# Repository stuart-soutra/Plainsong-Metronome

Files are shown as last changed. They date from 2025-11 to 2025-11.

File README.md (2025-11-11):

# Plainsong-Metronome
Open-source STM32-based digital stereo metronome
## Details
The Plainsong Metronome is a STM32F401-based audio platform, intended to be developed as a hi-fidelity digital stereo metronome for musicians.
The PCB contains two encoders intended to be used for UI navigation and volume control.
Four mechanical keyboard switches are included that are intended to control UI item selection and playback settings.
The PCB can be powered by a 12VDC 1A supply via, the DC barrel jack. 
Two 2.54mm pin header connectors are included for speaker outputs (L and R), as well as an extra 3-pin 2.54mm header (intended to be connected to a pane-mounted 3.4mm stereo TRS jack output for headphones).
The board houses an FFC connector to allow ribbon cable connection to a MIDAS OLED display.
A Micro B USB jack is included to allow firmware upgrade via. STM32 DFU, and potentially sample loading.
A mechanical enclosure design is available for the device (see 'Enclosure').
## Project Status
The project is currently in its B rev - board bring-up has been done in Rev A and Rev B has all changes implemented. 
I started this project to learn more about more complex 4-layer mixed-signal PCB design, so the full firmware was not my primary concern. I have therefore decided to make this project open-source, as I have learnt what I wanted to learn from it and if anyone else would like to dive deeper with the firmware, they can potentially also get something out of this project or take it further.
## Hardware Summary
### STM32F401CBU7 MCU
The MCU processes all IO and uses I2C, I2S and SPI to interface with the OLED, CODEC and Flash memory, respectively. The flash memory is included to expand audio sample storage capacity.
### MAX9867 Audio CODEC
The CODEC handles DAC duties for the system - samples are transmitted to it from the MCU via. I2S, then output to the audio amplifiers. Volume control is handled by the CODEC (with commands coming from the MCU).
### MAX9716 Audio Amplifiers
Two audio amps give differential audio outputs for the speakers (delivering 1.4W into 4 Ohms).
### MIDAS SSD1309ZC-Based OLED
The FFC connector on the board allows for connection of a 31-pin MIDAS OLED (MCOT128064B1V used during testing).
## Current Status
### Rev A
Board bring up was performed during Rev A. I have one Rev A board with all mods implemented that are required for the hardware to work - these changes have been implemented into the Rev B design. I have a number of Rev A boards (unmodded, unpopulated) - feel free to contact me if you would like one of these. I am happy to ship these to the UK if you would like to populate and mod them.
### Rev B
Rev B contains all of the mods from Rev A bring-up (see schematic for more details). The one untested part of the hardware that I have changed between rev's is the audio amplifier circuit. Rev B has a simplified circuit here, as I did not realise that the volume control could be done solely by the CODEC, so the digi-pots are no longer required.
## Untested Components
New Rev B audio amplifier circuit.
## Test Firmware Included
I have included the main test firmware file for STM32 Cube IDE. This includes simple drivers for some of the functions of each of the peripherals on the board that required testing during bring-up. The basic RTOS operation is also tested here. You will find the different test functions to be commented in/out.
## Firmware Build and Upload Process
The easiest way is using STM32 Cube IDE and USB DFU. Hold down the upload button and the SELECT button to access the DFU bootloader whilst power-cycling.
## Future Feature Wishlist
Feel free to help and contribute with these features:
- Audio amplifier circuit testing
- Full operational code
- Sample uploading option added
- External software for sample uploading
## Licence
This project is released under the CERN OHL V2 - Strongly Reciprocal Licence - see 'LICENCE.txt' for full terms.
## PCB Artwork Disclaimer
This project includes original fan artwork inspired by The Cure’s album Wish and Robert Smith’s imagery. It is used here non-commercially, as a tribute, for educational and artistic purposes.

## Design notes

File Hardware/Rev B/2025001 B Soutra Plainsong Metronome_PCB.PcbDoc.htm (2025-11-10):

Reporting Options

# File in Newer Format

Date | : | 26/05/2025
Time | : | 23:38:41
Filename | : | C:\Users\Stuart\OneDrive - Edinburgh Napier University\Altium Projects\2024001 A Soutra Plainsong Metronome\2024001 A Soutra Plainsong Metronome\2024001 A Soutra Plainsong Metronome_PCB.PcbDoc

Version | Warning
Release 23.6 | CAUTION - The PCB document contains Footprint parameters. These will be lost when opening the document in a version of Altium Designer that does not support this functionality.
Release 23.10 | CAUTION - This document contains rules defined using the Constraint Manager. These will appear as standard query-based rules in this version of the software. If you save the PCB document in this older version, then all Constraint Manager data structure information will be lost.

This file was generated by a later version of the software

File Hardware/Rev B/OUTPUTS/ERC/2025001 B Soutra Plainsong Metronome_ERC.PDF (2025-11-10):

### Electrical Rules Check Report

Class | Document | Message
Warning | Block Diagram.SchDoc | Net MCLK_EN has no driving source (Pin R5-1, Pin U1-10, Pin X2-1)
Warning | Block Diagram.SchDoc | Nets Wire D_N has multiple names (Net Label D_N, Sheet Entry Designator-D-(I/O) (2))
Warning | Block Diagram.SchDoc | Nets Wire D_P has multiple names (Net Label D_P, Sheet Entry Designator-D+(I/O) (2))
Warning | Power.SchDoc | Off grid J1 at 912.992mil,6699.213mil
Warning | MCU.SchDoc | Off grid Net Label BOOT0 at 4512.258mil,5300mil
Warning | MCU.SchDoc | Off grid Net Label D_N at 3000.661mil,3600mil
Warning | Power.SchDoc | Off grid Pin J1-1 at 1112.992mil,6799.213mil
Warning | Power.SchDoc | Off grid Pin J1-2 at 1112.992mil,6599.213mil
Warning | Power.SchDoc | Off grid Pin J1-3 at 1112.992mil,6699.213mil
Warning | Power.SchDoc | Off grid Pin SW1-1 at 1829.135mil,6799.216mil
Warning | Power.SchDoc | Off grid Pin SW1-2 at 2429.135mil,6799.216mil
Warning | IOa.SchDoc | Off grid Port D+ at 4099.339mil,6600mil
Warning | MCU.SchDoc | Off grid Port TEMPO_LED at 3390.3mil,3300mil
Warning | Power.SchDoc | Off grid Power Object GND at 1112.992mil,6405.512mil
Warning | Power.SchDoc | Off grid Power Object GND at 4500mil,5618.113mil
Warning | Block Diagram.SchDoc | Off grid Sheet Symbol Designator at 2700mil,6055.515mil
Warning | Power.SchDoc | Off grid SW1 at 2129.135mil,6799.216mil
Thursday 6 Nov 2025 4:35:00 PM | Page 1 of 1

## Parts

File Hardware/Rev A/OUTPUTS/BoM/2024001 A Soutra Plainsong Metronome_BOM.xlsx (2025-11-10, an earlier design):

 |  | Bill of Materials for: |  | Bill of Materials for Project [2024001 A Soutra Plainsong Metronome.PrjPcb] (No PCB Document Selected)
 |  | Source Data From: |  | 2024001 A Soutra Plainsong Metronome.PrjPcb
 |  | Variant: |  | None
 |  | Report Date: |  | 22/10/2024 | 09:38
 | soutraelectronics@gmail.com
 | 14 Ryehill Gardens
 | Edinburgh
 | EH68ER
 | +44(0)7874693650
 |  |  |  |  |  |  | Primary Supplier |  |  | Secondary Supplier |  |  | Alternative Part Details
Designator | Manufacturer Part Number | Value | Manufacturer | Footprint | Quantity | Notes | Supplier | Supplier Part Number | Pricing | Supplier 1 | Supplier Part Number 1 | Pricing 1 | Alternative Part | Alternative Part Manufacturer | Alternative Part Supplier | Alternative Part Supplier Part Number
C3, C4, C9, C13, C42, C43 | CL31B475KAHNNNE | 4.7uF | Samsung | CC1206-IPC_A | 6 |  | Digikey | 1276-1055-1-ND | 1=0.18, 10=0.116, 50=0.0732, 100=0.0585, 500=0.04228, 1000=0.0374 (USD) | Farnell | 3013532 | 5=0.08, 50=0.05
C6 | GRM21BR61A226ME51L | 22uF | Murata | CAPC2012X14L | 1 |  |  |  |  | Farnell | 2494270 | 5=0.192, 50=0.09 | C2012X5R1A226M125AB | TDK | Farnell | 2525131
C7, C8, C18, C22, C23, C24, C26, C27, C28, C29, C37, C38, C41 | CC0402KRX5R6BB105 | 1uF | Yageo | CAPC1005X06L | 13 |  | Farnell | 1458896 | 10=0.039, 100=0.023 | Digikey | 311-1439-1-ND | 1=0.08, 10=0.058, 50=0.034, 100=0.027 | 0402ZD105KAT2A | KYOCERA AVX | Farnell | 1740588
C10, C11, C12, C14, C15, C16, C17, C19, C25, C44 | 0402X104M160CT | 100nF | Walsin Technologies | CAPC1005X06L | 10 |  | Farnell | 2524808 | 10=0.0047, 100=0.0043 | Digikey | 1292-0402X104M160CT-ND | 1=0.08, 10=0.023, 50=0.013, 100=0.01 | 885012105016 | WURTH | Farnell | 2533933
C20, C21 | CC0402CRNPO9BN5R0 | 5pF | Yageo | CAPC1005X06L | 2 |  |  |  |  | Farnell | 3369083 | 10=0.014, 100=0.008 | GJM1555C1H5R0CB01D | Murata | Farnell | 3346199
C30 | CC0402MRX5R5BB225 | 2.2uF | Yageo | CAPC1005X06L | 1 |  |  |  |  | Farnell | 3369189 | 10=0.0794, 100=0.0451 | MC0402X225M6R3CT |  | Farnell | 1759376
C31, C32, C39, C40 | CC0402KPX7R9BB221 | 220pF | Yageo | CAPC1005X06L | 4 |  |  |  |  | Farnell | 4254872 | 10=0.0069, 500=0.0055, 2500=0.0042, 10000=0.003, 25000=0.0029, 50000=0.0028, 250000=0.0027, 500000=0.0026 (GBP) | MC0402B221K500CT |  | Farnell | 1758981
C33, C34, C35, C36 | TAJR225K016RNJ | 2.2uF | AVX Interconnect / Elco | CAPC2113X120X50ML20T30 | 4 |  |  |  |  | Farnell | 2112773 | 5=0.3684, 50=0.2592
D1 | SMAJ13CAHM3_A/H |  | Vishay | SODFL511X229-2N | 1 |  |  |  |  | Farnell | 3530003 | 5=0.168, 10=0.146, 100+0.122
D4, D5, D6, D7, D10 | MP008282 |  | Multicomp | DIOC_0603_1706X06L | 5 |  | Farnell | 3796313 | 5=0.0713, 10=0.0611, 100=0.0476 |  |  |  | LG Q396-PS-35 | AMS OSRAM GROUP | Farnell | 2575345
F1 | MP001600 |  | Multicomp | FUSE_3216X08L | 1 |  | Farnell | 3285103 | 5=0.094, 50=0.0739, 250=0.0627, 500=0.0559, 1500=0.0459 (GBP)
J1 | 694103303002 |  | Wurth Electronics | WURTH_694106301002 | 1 |  | Farnell | 2472149 | 1=1.14, 10=0.84, 100=0.78 | Digikey | 732-5930-ND | 1=0.81, 10=0.77, 50=0.68, 100=0.63
J2, J3 | 22-05-7028 |  | Molex | J_MOLEX_22-05-7028 | 2 |  |  |  |  | Farnell | 9731601 | 1=0.78, 10=0.64, 50=0.57, 100=0.50
J4 | 105017-0001 |  | Molex | 1050170001_USB-MICRO-B_V | 1 |  | Farnell | 3500663 | 1=0.97 | Rs | 8486764 | 5=0.754, 75=0.67
J5 |  |  |  | J_GENERIC_PIN-HEADER_2.54_1X3 | 1
J6 | 3-1734592-1 |  | TE Connectivity | AMP-TE_3-1734592-1 | 1 |  |  |  |  | Farnell | 3398664 | 1=1.44, 10=1.26, 100=1.15
R1, R14, R15, R16, R17, R18, R19, R20, R21, R22, R23, R24, R25, R26, R27, R28, R29 | MC0063W06030R | 0R | Multicomp | RESC_0603_1608X06L | 17 |  | Farnell | 9331662 | 10=0.007, 100=0.006 |  |  |  | MCWR06X000 PTL | Multicomp Pro | Farnell | 2447743
R2, R3 | RK73B1JTTD103J | 10kR | KOA Speer | RESC_0603_1608X06L | 2 |  | Farnell | 4009056 | 10=0.009, 100=0.003 | Digikey | 2019-RK73B1JTTD103JCT-ND | 1=0.08, 10=0.012, 50=0.0078, 100=0.0064 | RMCF0603FT10K0 | Stackpole Electronics Inc | Digikey | RMCF0603FT10K0CT-ND
R4, R5, R6, R8, R9, R31, R32, R33, R34, R35, R36, R37, R42, R43, R44 | RC0805JR-0710KL | 10kR | Yageo | RESC_0805_2013X50X30LL20T20 | 15 |  | Farnell | 9234136 | 10=0.013, 100=0.007, 500=0.006 | Digikey | 311-10KARCT-ND | 1=0.08, 10=0.018, 50=0.011, 100=0.009 | MCMR08X103 JTL |  | Farnell | 2073612
R7 | CRGH0805F2K7 | 2.7k | TE Connectivity | RESC_0805_2013X50X30LL20T20 | 1 |  | Farnell | 2332077 | 10=0.0381 | Mouser | 279-CRGH0805F2K7 | 1=0.096, 10=0.065, 100=0.033 | MC01W08051100R | Multicomp Pro | Farnell | 9332375
R10, R11, R12, R13 | MCMR06X512JTL | 5.1kR | Multicomp | RESC_0603_1608X06L | 4 |  |  |  |  | Farnell | 2073528 | 10=0.0065, 100=0.0056, 500=0.0047, 1000=0.004, 2500=0.0027, 5000=0.0021, 25000=0.0016, 50000=0.0013 (GBP) | MCMR06X5101FTL |  | Farnell | 2073522
R30 | RC0402FR-07590KL | 590kR | Yageo | RESC_0402_1005X40X25LL05T10 | 1 |  |  |  |  | Farnell | 3951243 | 10=0.0096, 100=0.0055 | CRCW0402590KFKED | Vishay | Farnell | 2141013
R38, R39, R40, R41, R45 | CRCW0805100RFKTA | 100R | Vishay Dale | RESC_0805_2013X50X30LL20T20 | 5 |  | Farnell | 1652906 | 10=0.06, 100=0.026 | Mouser | 71-CRCW0805-100 | 1=0.12, 10=0.042, 100=0.027 | CRCW0805100RFKEA | VISHAY | Farnell | 1469862
R46 | ERJ-PA3F91R0V | 91 | Panasonic | RESC_0603_1608X06L | 1 |  | Farnell | 2335962 | 10=0.05, 100=0.03
SW1 |  |  |  | SW_PTH-Wire-to-Board-D1.2 | 1
SW2, SW7 | PEC12R-4220F-S0024 |  | Bourns | BOURNS_PEC12R-4220F-S0024 | 2 |  | Farnell | 2663532 | 1=1.7, 5=1.49, 10=1.26, 20=1.16, 40=1.06, 75=0.97 | Digikey | PEC12R-4220F-S0024-ND | 1=1.28, 5=1.21, 10=1.14, 25=1.04, 75=0.97
SW3, SW4, SW5, SW6 | MX1A-11NW |  | Cherry | CHERRY_MX1A-11NW | 4 |  | Mech Boards | ACHERSW0315325 | 10=5
TP1, TP2, TP3, TP4, TP5, TP6, TP7, TP8, TP9, TP10, TP11, TP12, TP13, TP14, TP15, TP16, TP17, TP18, TP19, TP20, TP21, TP22, TP23, TP24, TP25, TP26, TP27, TP28, TP29, TP30, TP31, TP32 |  |  |  | TP_CIRCLE_R1 | 32
U1 | STM32F401CBU7 |  | STMicroelectronics | UFQFPN50P700X700X60_HS-49L | 1 |  | Farnell | 2469576 | 1=3.42 | Digikey | STM32F401CBU7 | 1=4.88, 10=4.38, 25=4.14, 80=3.59
U2 | AT45DB641E-MHN-Y |  | Adesto Technologies | QFN127P600X500X60_HS-9L | 1 |  | Farnell | 2910029 | 1=5.02, 10=4.15, 25=3.97, 50=3.80, 100=3.62 | Digikey | 1265-1227-ND | 1=4.65, 10=4.24, 25=4.16, 40=4.13, 80=3.70
U3 | MAX9867ETJ+T |  | Maxim | TQFN50P500X500X80_HS-33L | 1 |  | Farnell | 2517273 | 1=2.92, 10=2.45, 25=2.3, 100=2.15 | Digikey | MAX9867ETJ+TCT-ND | 1=2.95, 10=2.65, 25=2.5, 100=2.17
U4, U5, U8, U9 | MCP4542T-103E/MF |  | Microchip | DFN-MF8 | 4 |  |  |  |  | Farnell | 3102788 | 1=0.998, 25=0.84, 100=0.78
U6, U7 | MAX9716ETA+T |  | Maxim | TDFN300X300X80_HS-9L | 2 |  | Farnell | 2516304 | 1=1.41, 10=1.26, 25=1.19, 100=0.982 | Digikey | MAX9716ETA+TCT-ND | 1=1.28, 10=1.15, 25=1.08, 100=0.92
U10 | TPD2EUSB30ADRTR |  | Texas Instruments | DRT0003A | 1 |  |  |  |  | Farnell | 3116501 | 5=0.53, 10=0.4, 100=0.22
VREG1 | TLE4284DV50ATMA1 |  | Infineon | TO252-3-11_L | 1 |  |  |  |  | Farnell | TLE4284DV50ATMA1 | 5=1.49, 50=1.38, 100=1.27
VREG2 | AZ1117CH-3.3TRG1 |  | Diodes | SOT230P700X180-4L | 1 |  | Farnell | 3483073 | 5=0.42, 10=0.25, 100=0.12 | Digikey | AZ1117CH-3.3TRG1DICT-ND | 1=0.36, 10=0.27, 25=0.23, 100=0.15
VREG3 | AP7370-18FDC-7 |  | Diodes | U-DFN2020EP65P201X201X63_HS-7L | 1 |  | Farnell | 3864505 | 5=0.53, 10=0.42, 100=0.23 | Mouser | 621-AP7370-18FDC-7 | 1=0.38, 10=0.271, 100=0.19
X1 | MCSJK-7E-24.00-8-10-60-B-10 | 24MHz | Multicomp | OSCSC1-85x1-55P2-55X2-05Y0-05_4MFR | 1 |  |  |  |  | Farnell | 2853878 | 5=0.232, 50=0.188, 250=0.165, 500=0.15, 1500=0.133, 3000=0.129, 15000=0.125, 30000=0.123 (GBP)
X2 | MCSJK-3N-12.288-3.3-50-C |  | Multicomp | X_MULTICOMP_MCSJK-3N-12.288-3.3-50-C | 1 |  |  |  |  | Farnell | 2854277 | 5=0.644, 50=0.522, 250=0.455, 500=0.442, 1500=0.436, 3000=0.43, 15000=0.421, 30000=0.413 (GBP)
Note: All prices in GBP |  |  |  | Total Number of Items: |  |  | TOTAL COST (Primary Supplier Only): |  |  | TOTAL COST (Secondary Supplier Only):

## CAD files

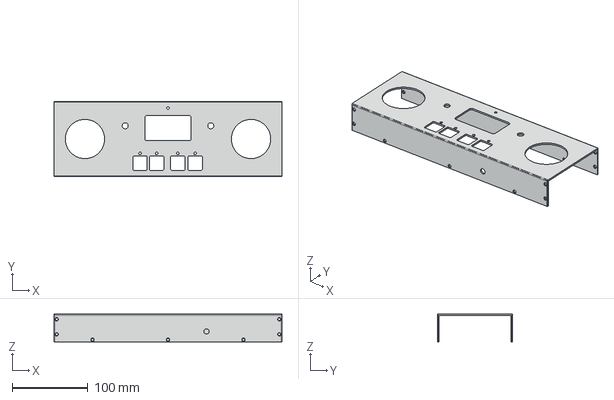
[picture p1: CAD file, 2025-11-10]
Mechanical/Soutra Plainsong Metronome (Alu).FCStd
302.0 x 100.0 x 37.0 mm

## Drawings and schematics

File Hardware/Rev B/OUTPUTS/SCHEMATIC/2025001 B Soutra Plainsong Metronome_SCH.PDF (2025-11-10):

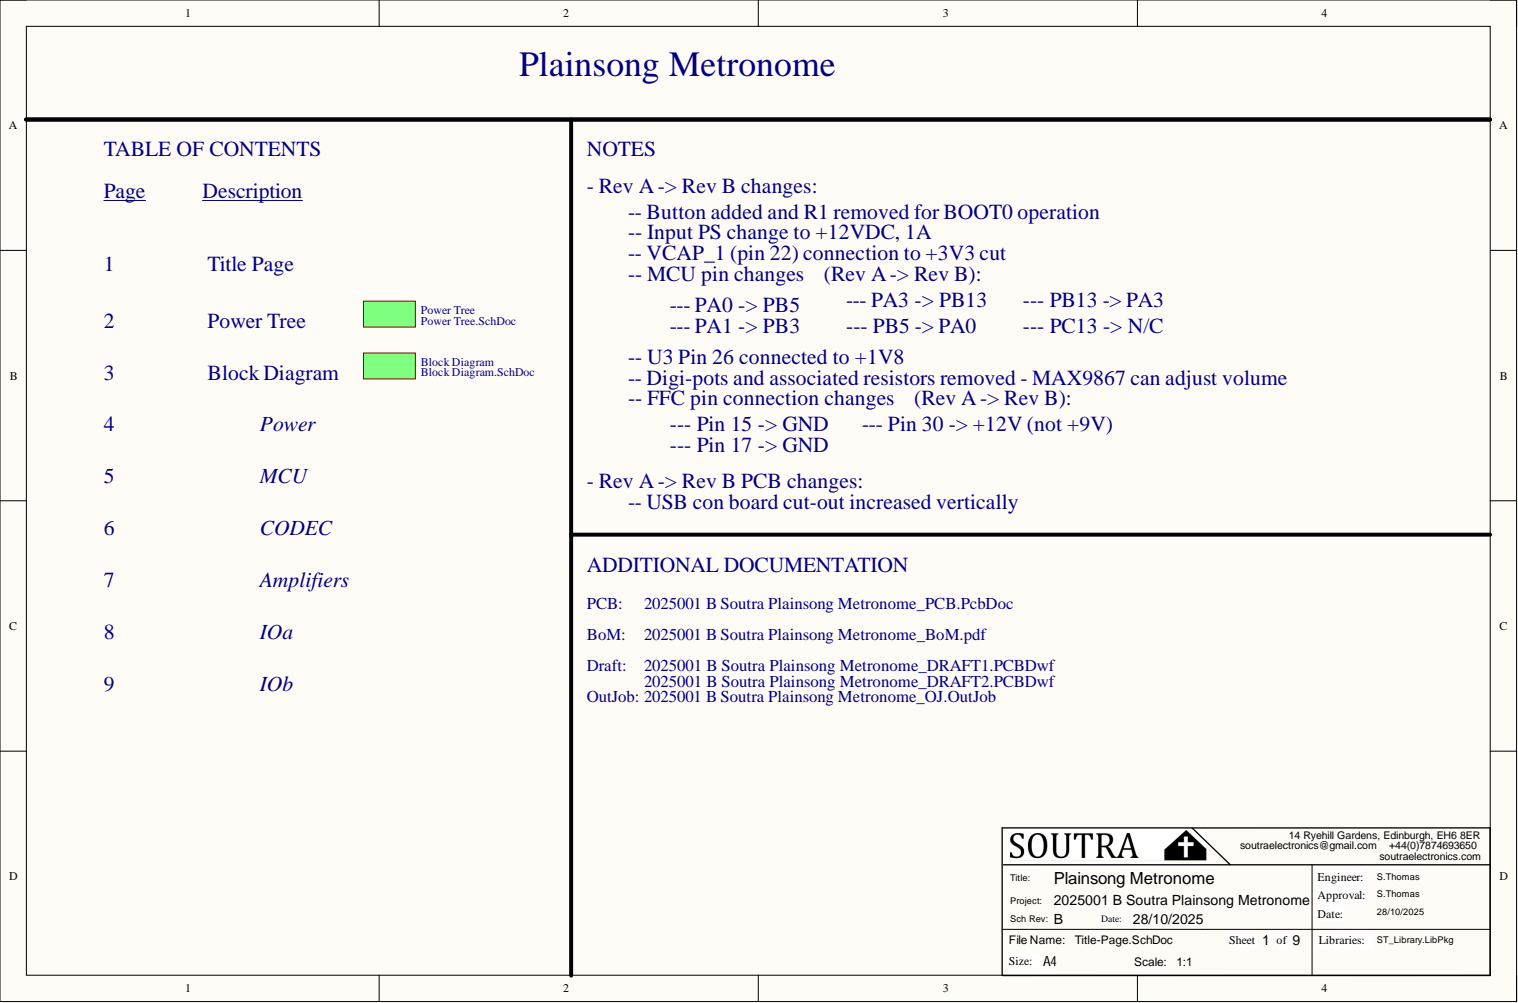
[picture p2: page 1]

NOTES
- Rev A -> Rev B changes:
-- Button added and R1 removed for BOOT0 operation -- Input PS change to +12VDC, 1A -- VCAP_1 (pin 22) connection to +3V3 cut -- MCU pin changes (Rev A -> Rev B):

-- U3 Pin 26 connected to +1V8 -- Digi-pots and associated resistors removed - MAX9867 can adjust volume -- FFC pin connection changes (Rev A -> Rev B):

Power Tree Power Tree.SchDoc

Block Diagram Block Diagram.SchDoc

- Rev A -> Rev B PCB changes: -- USB con board cut-out increased vertically

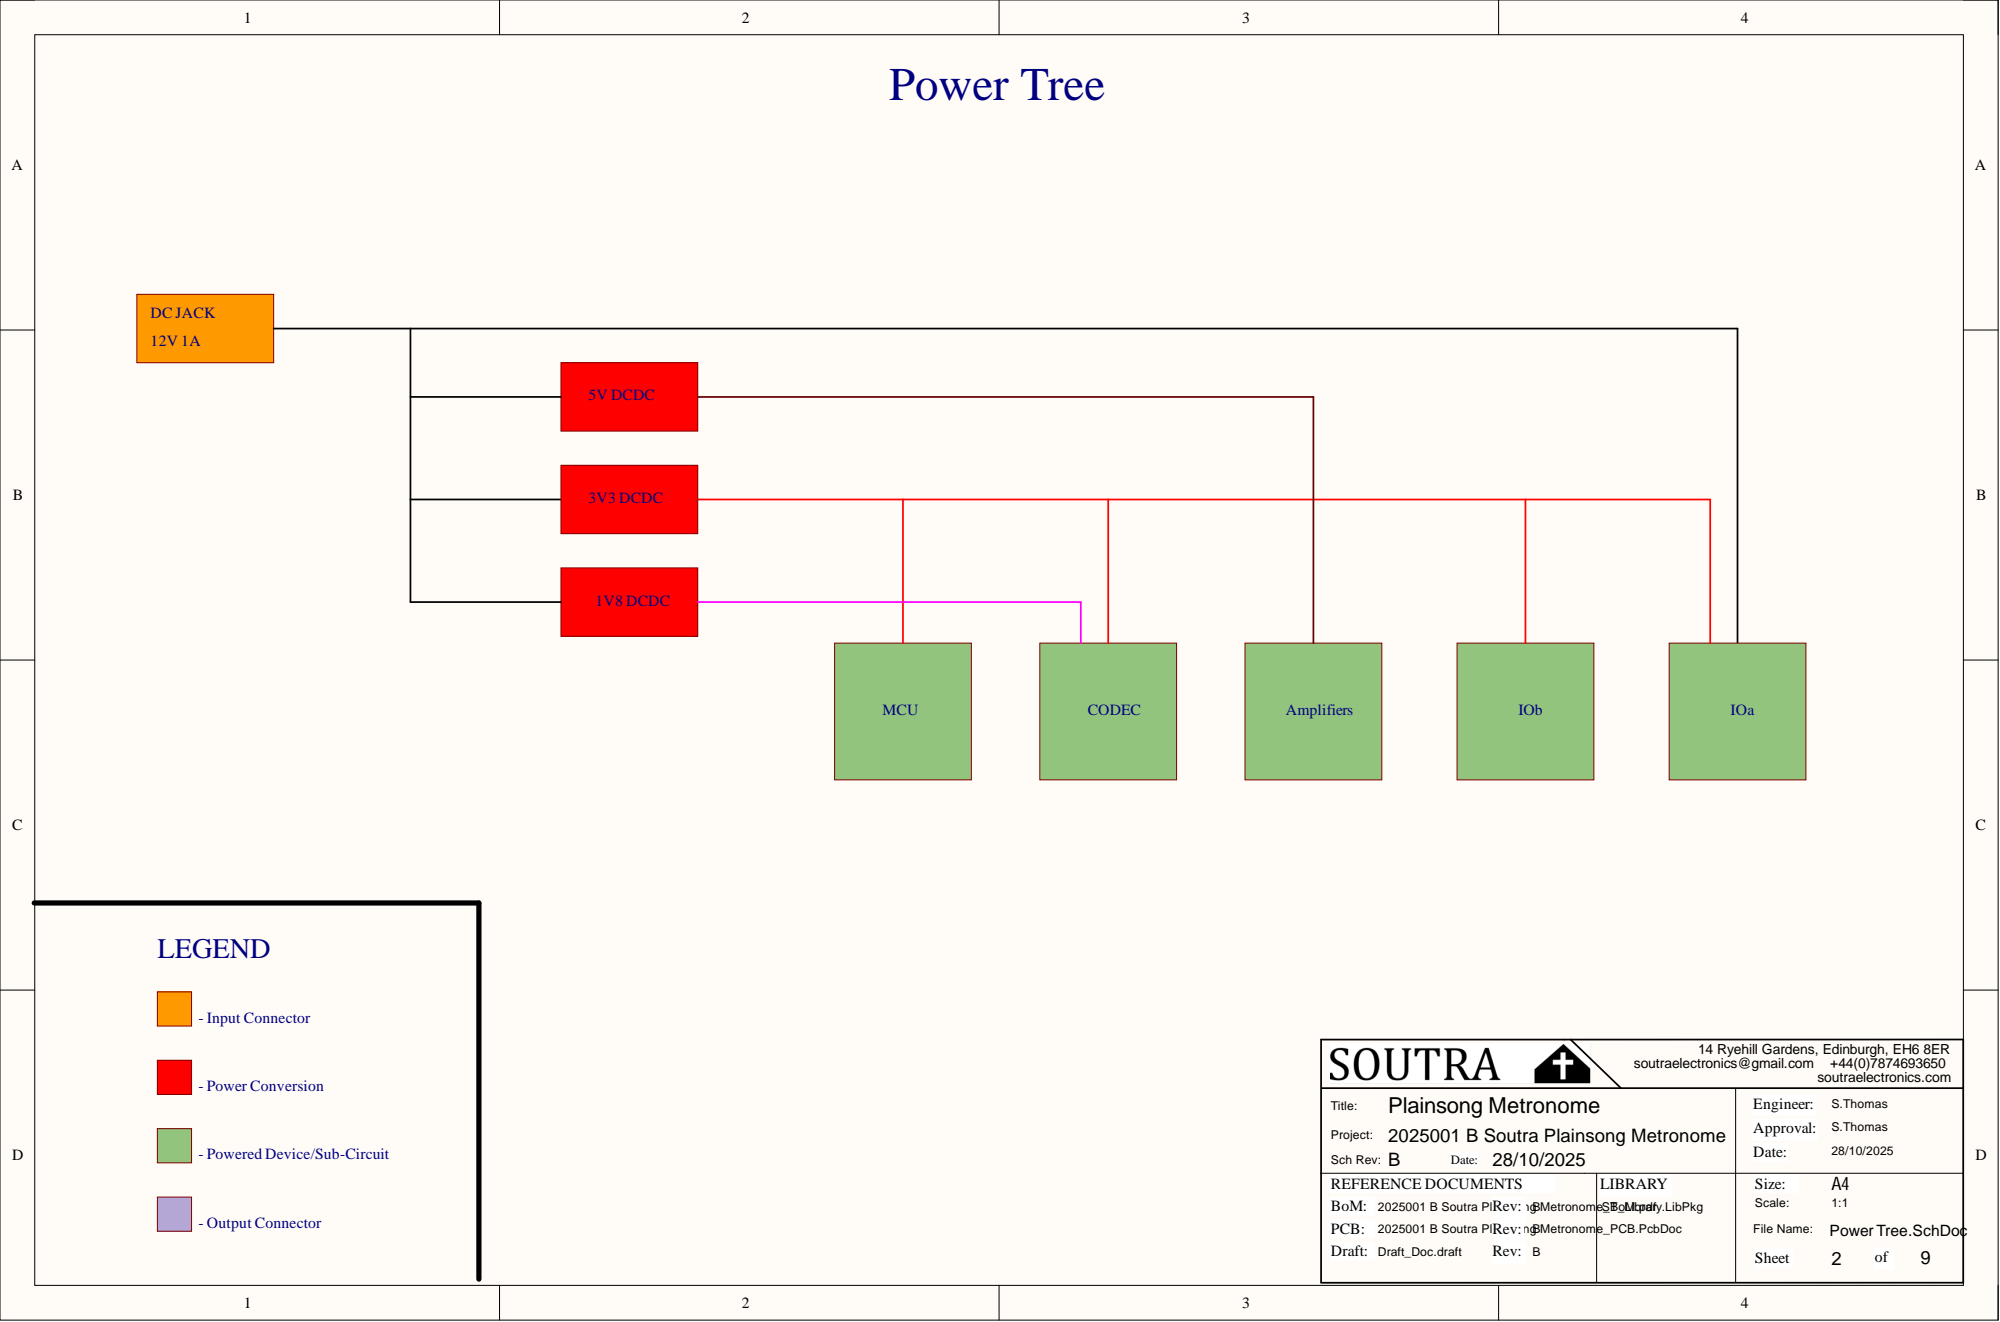
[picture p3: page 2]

- Powered Device/Sub-Circuit

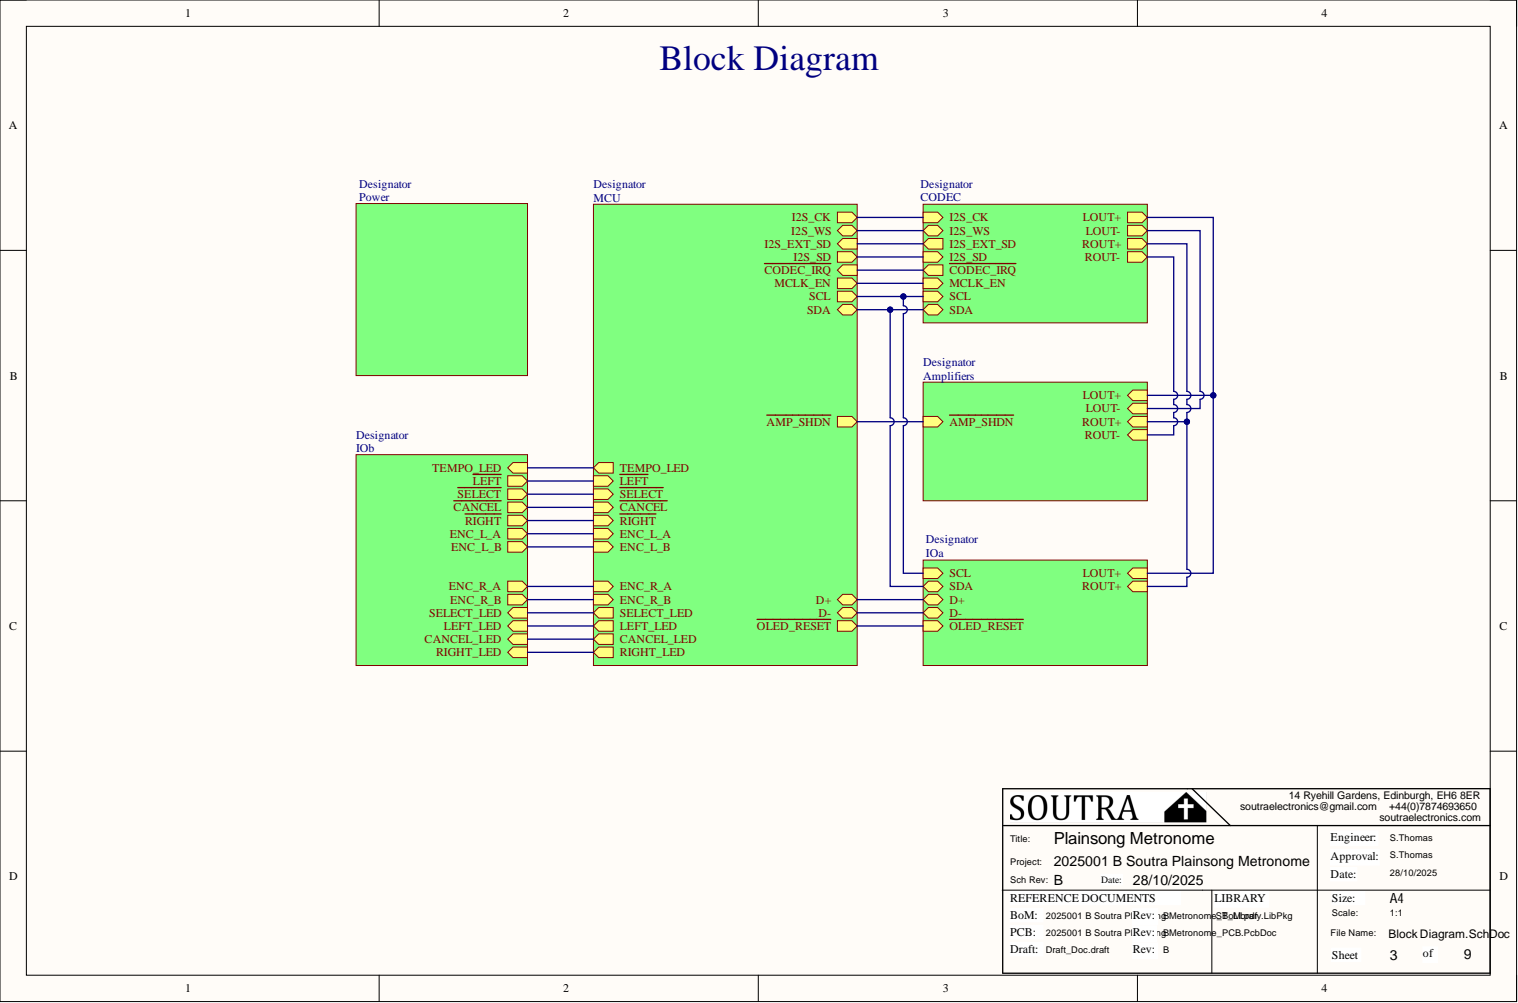
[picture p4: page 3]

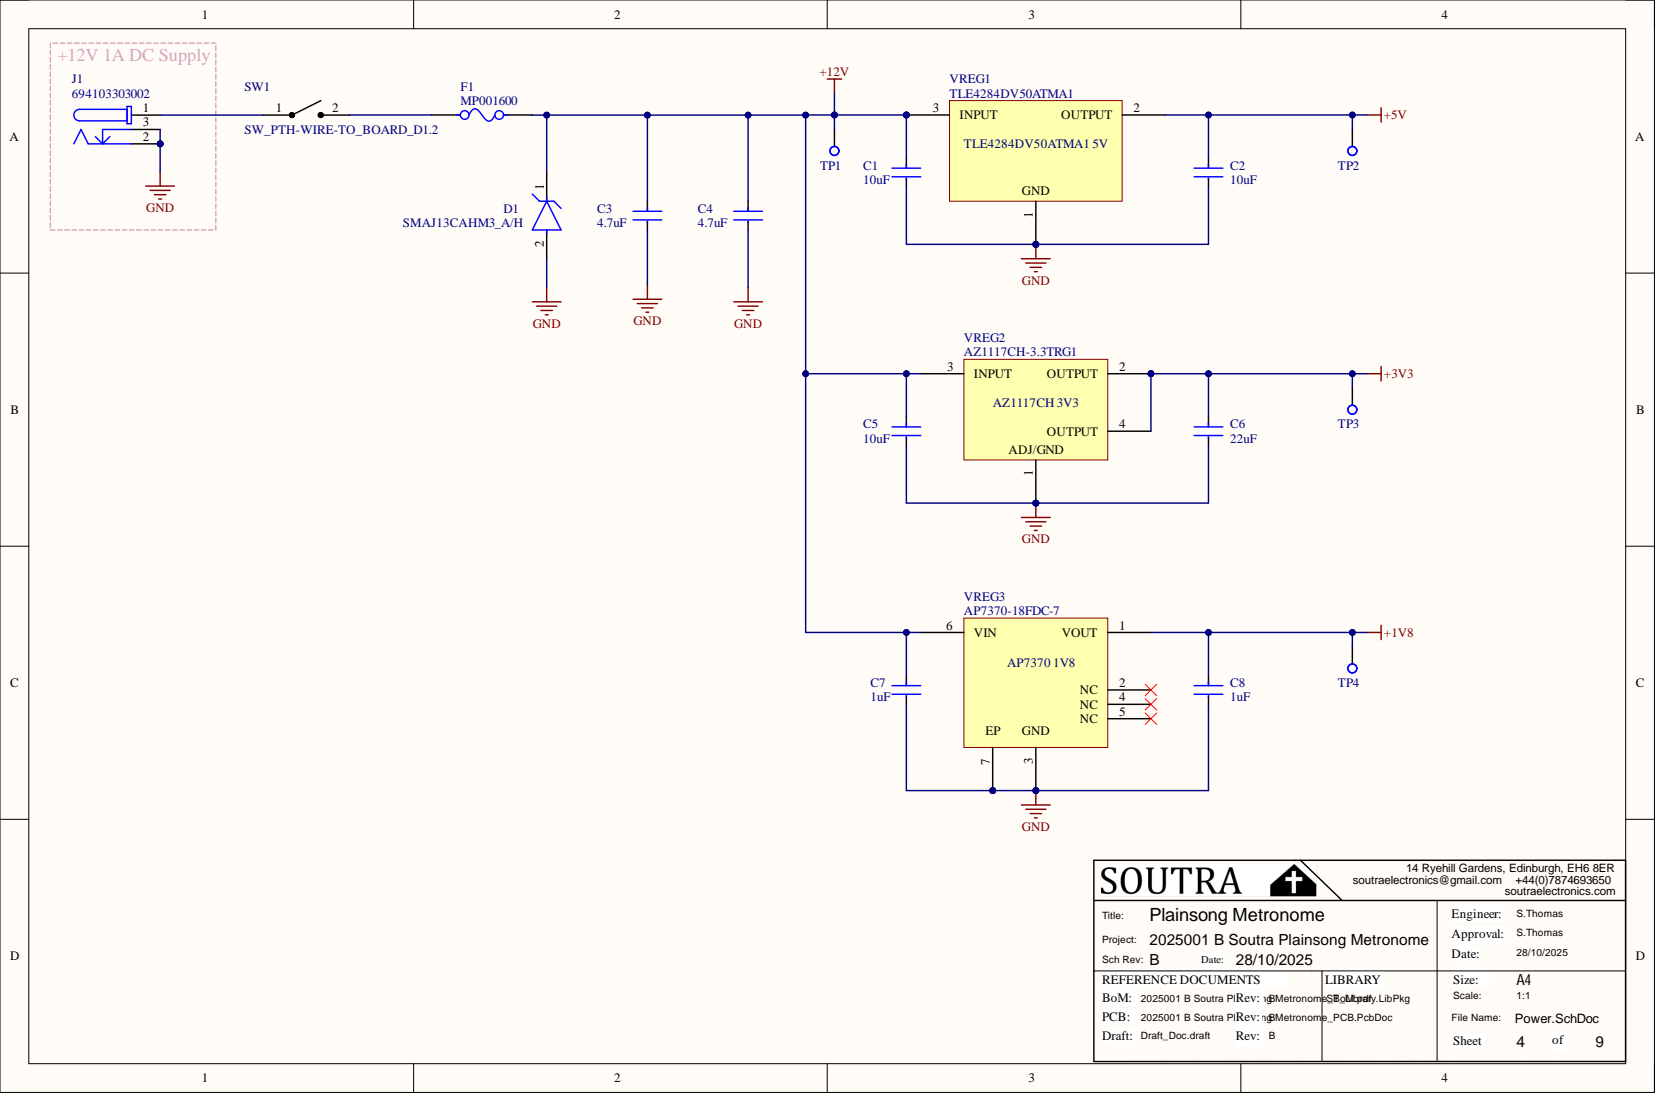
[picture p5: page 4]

Plainsong Metronome T itl e Pro j e ct: 2025001 B Soutra Plainsong Metronom e

REFERE NCE D OCUME N T S | LIBRA RY | bPk g c | Size : | 1:1 e : Power .Sc h D o c

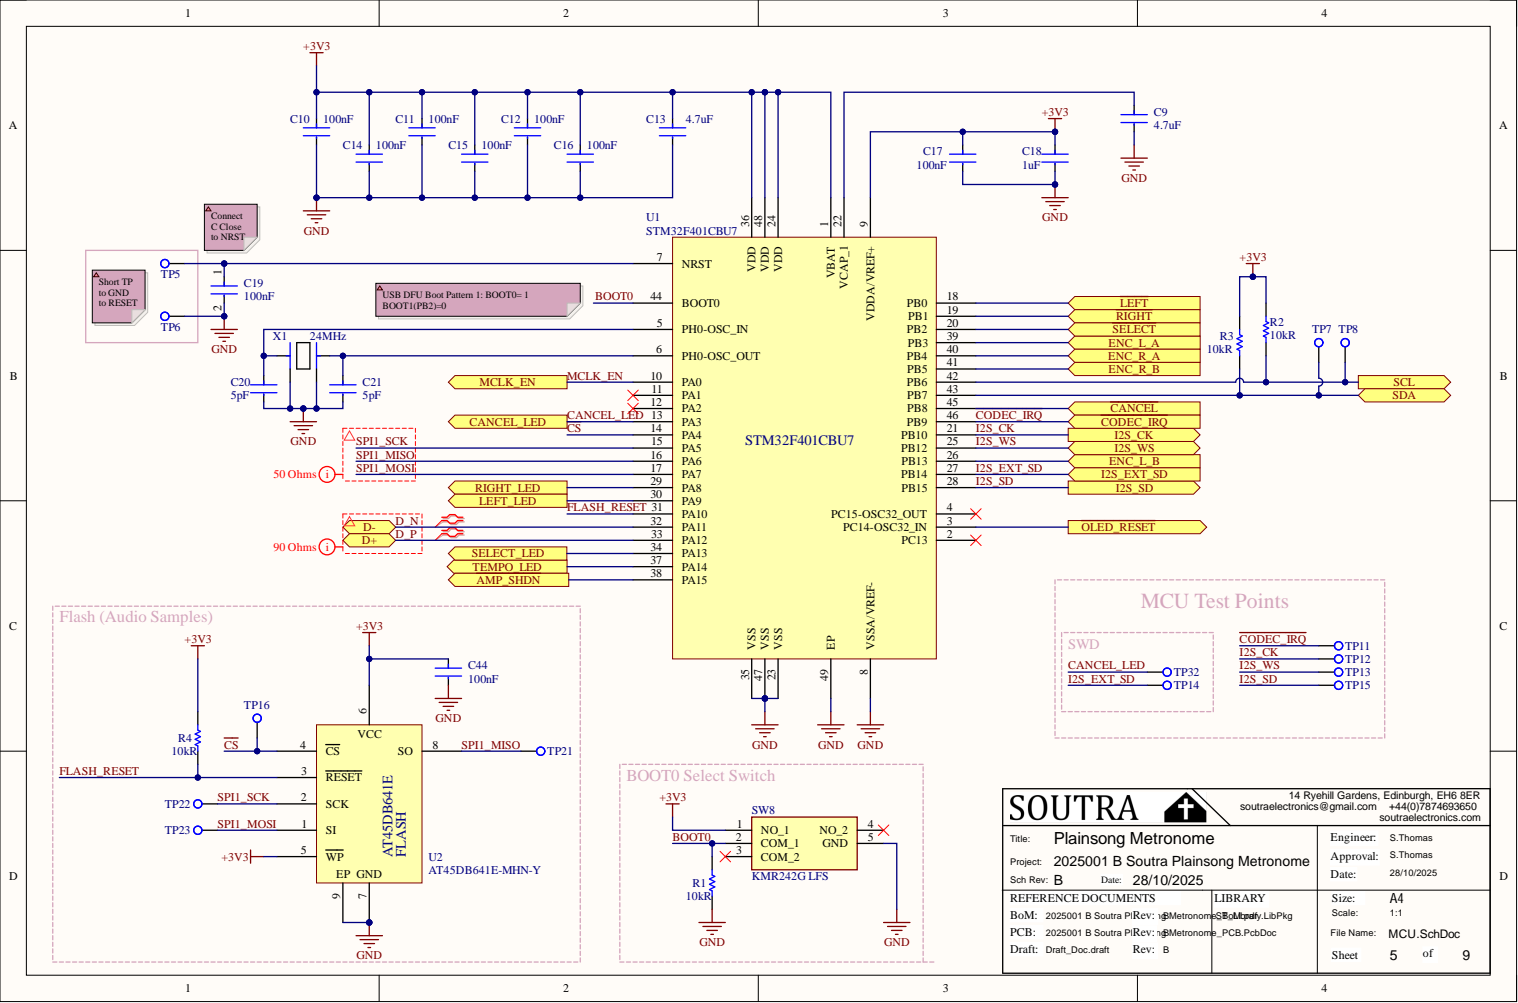
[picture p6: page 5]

VSSA/VREF- 8 VDDA/VREF+ 9

USB DFU Boot Pattern 1: BOOT0= 1
BOOT1(PB2)=0

X1 | 24MHz | PH0-OSC_OUT 6

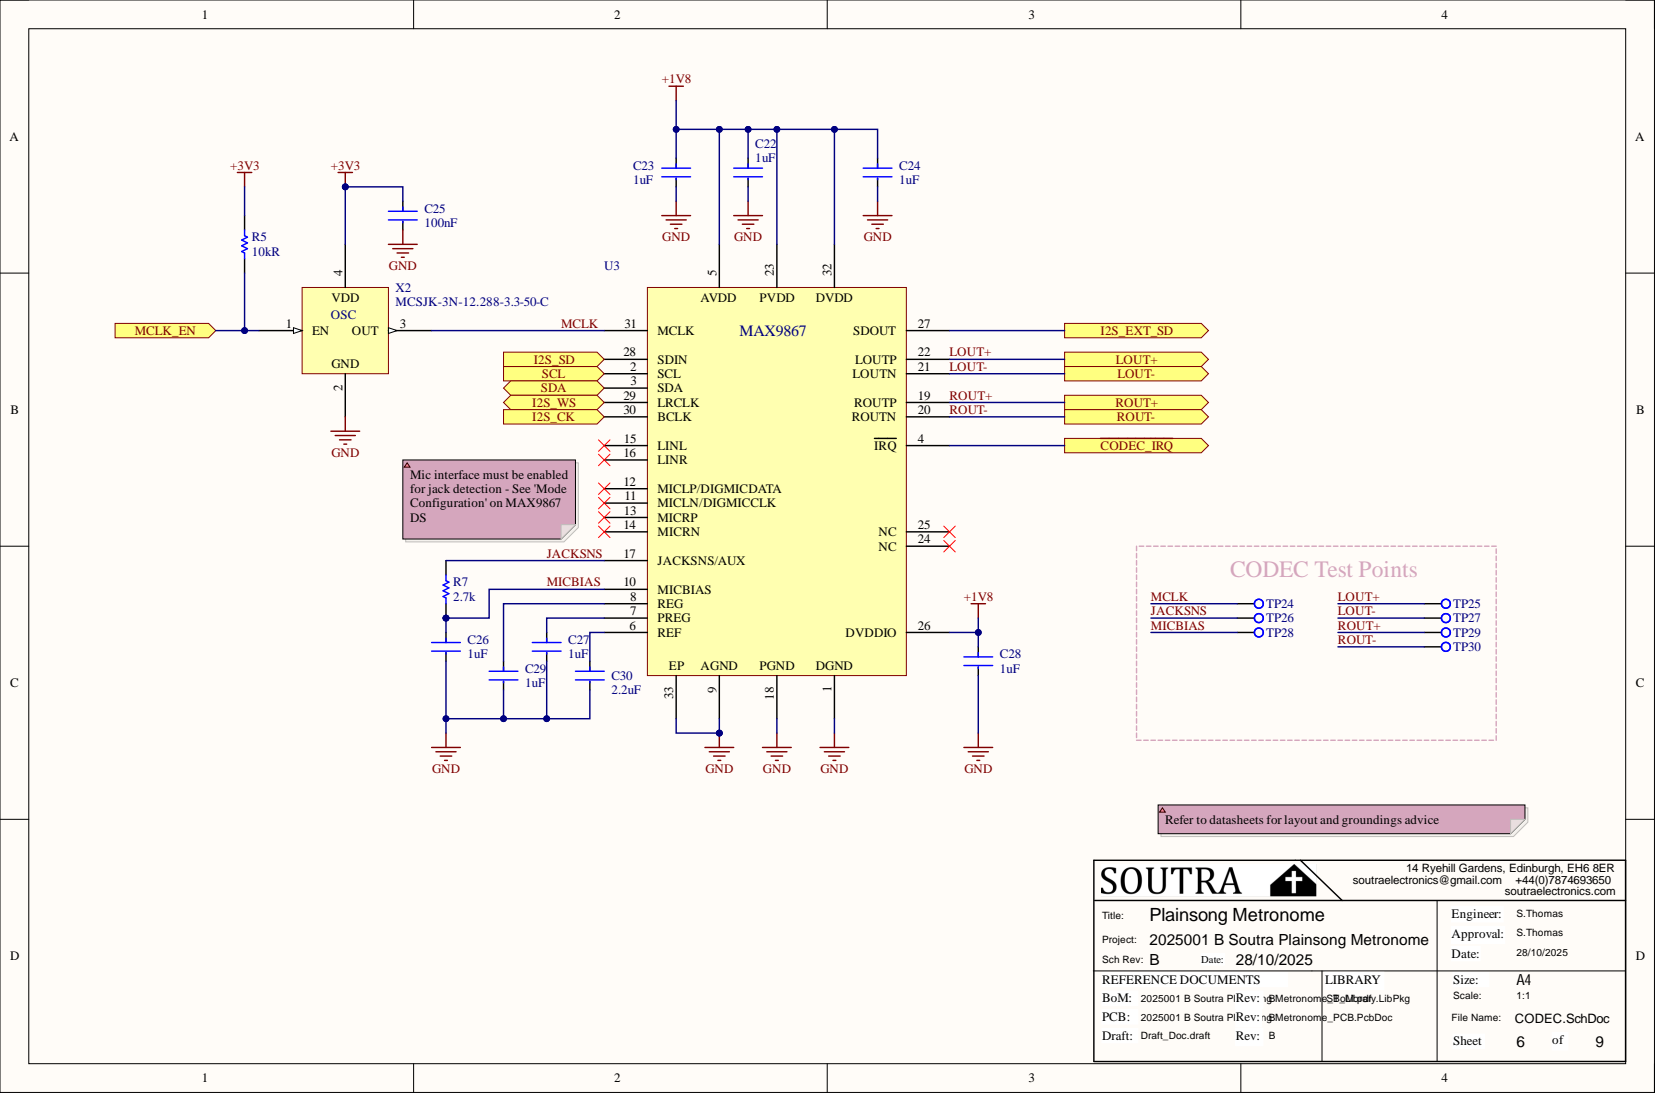
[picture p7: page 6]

Plainsong Metronome T itl e Pro j e ct: 2025001 B Soutra Plainsong Metronom e

REFERE NCE D OCUME N T S | LIBRA RY | bPk g c | Size : | 1:1 e : CODEC . S c h D o c

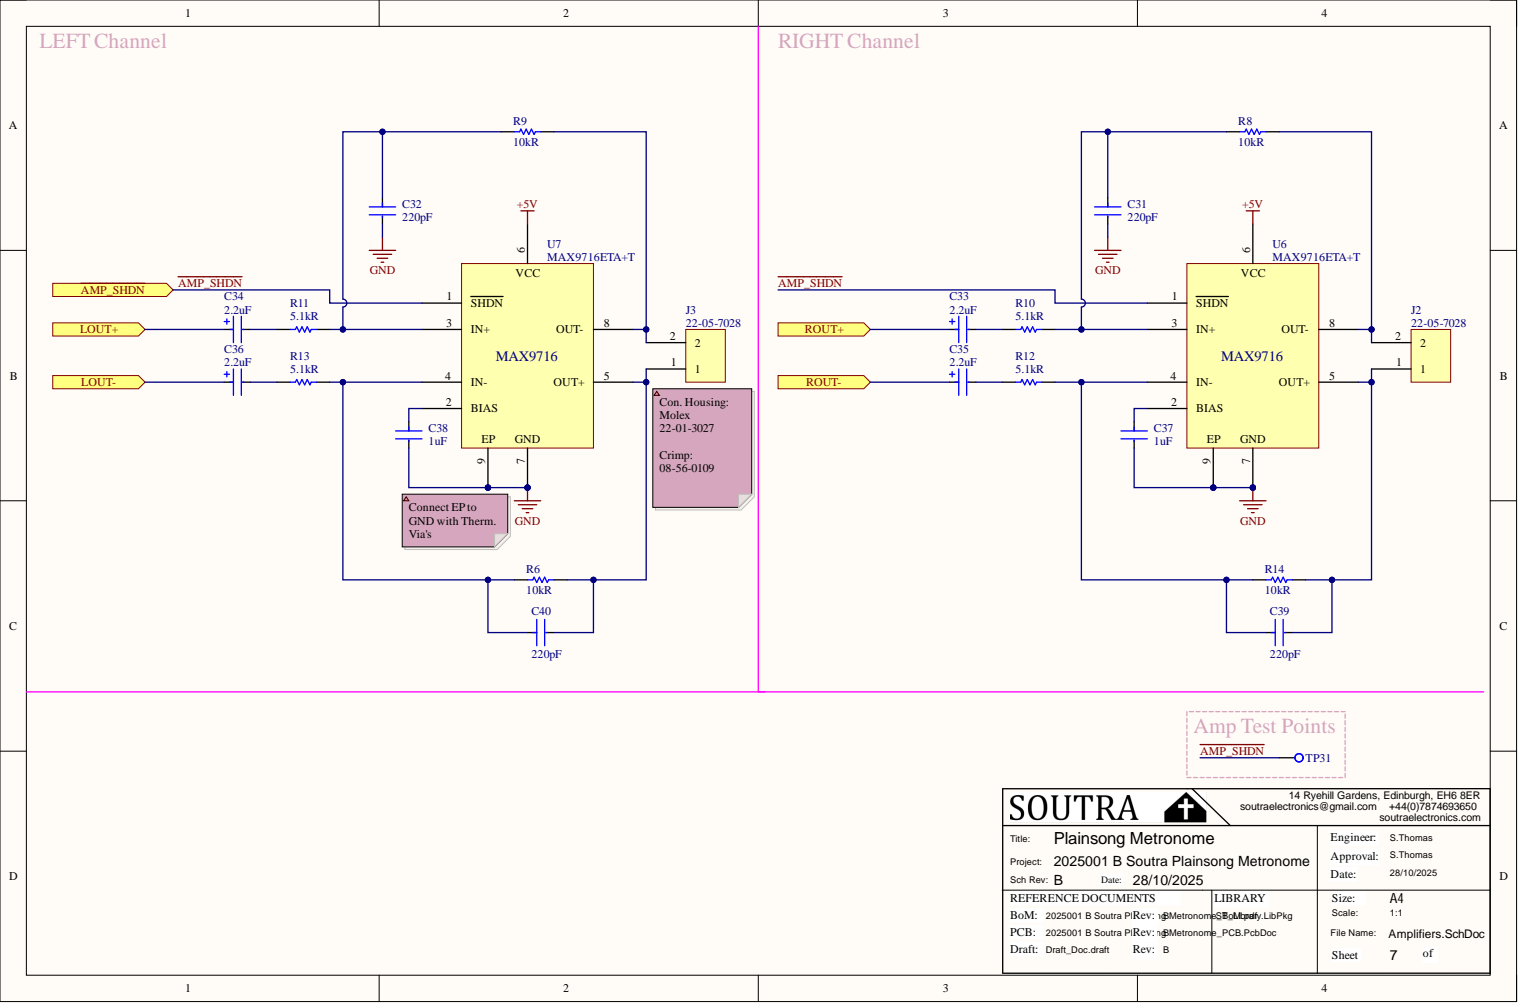
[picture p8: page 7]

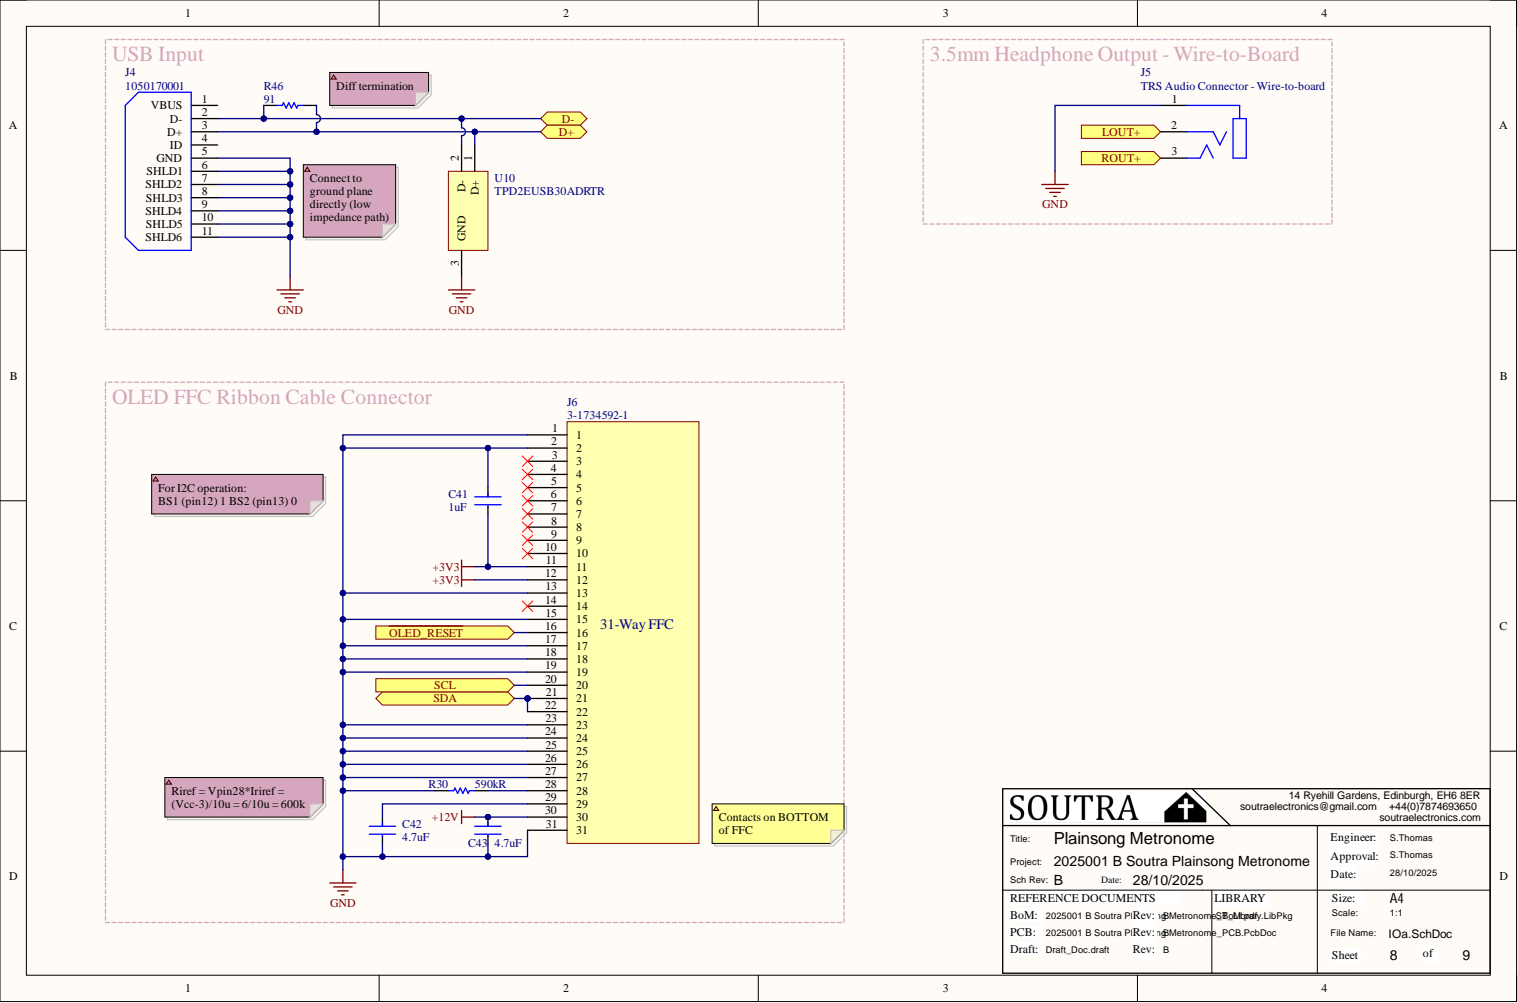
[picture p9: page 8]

TRS Audio Connector - Wire-to-board

OLED FFC Ribbon Cable Connector

2 2
3 3

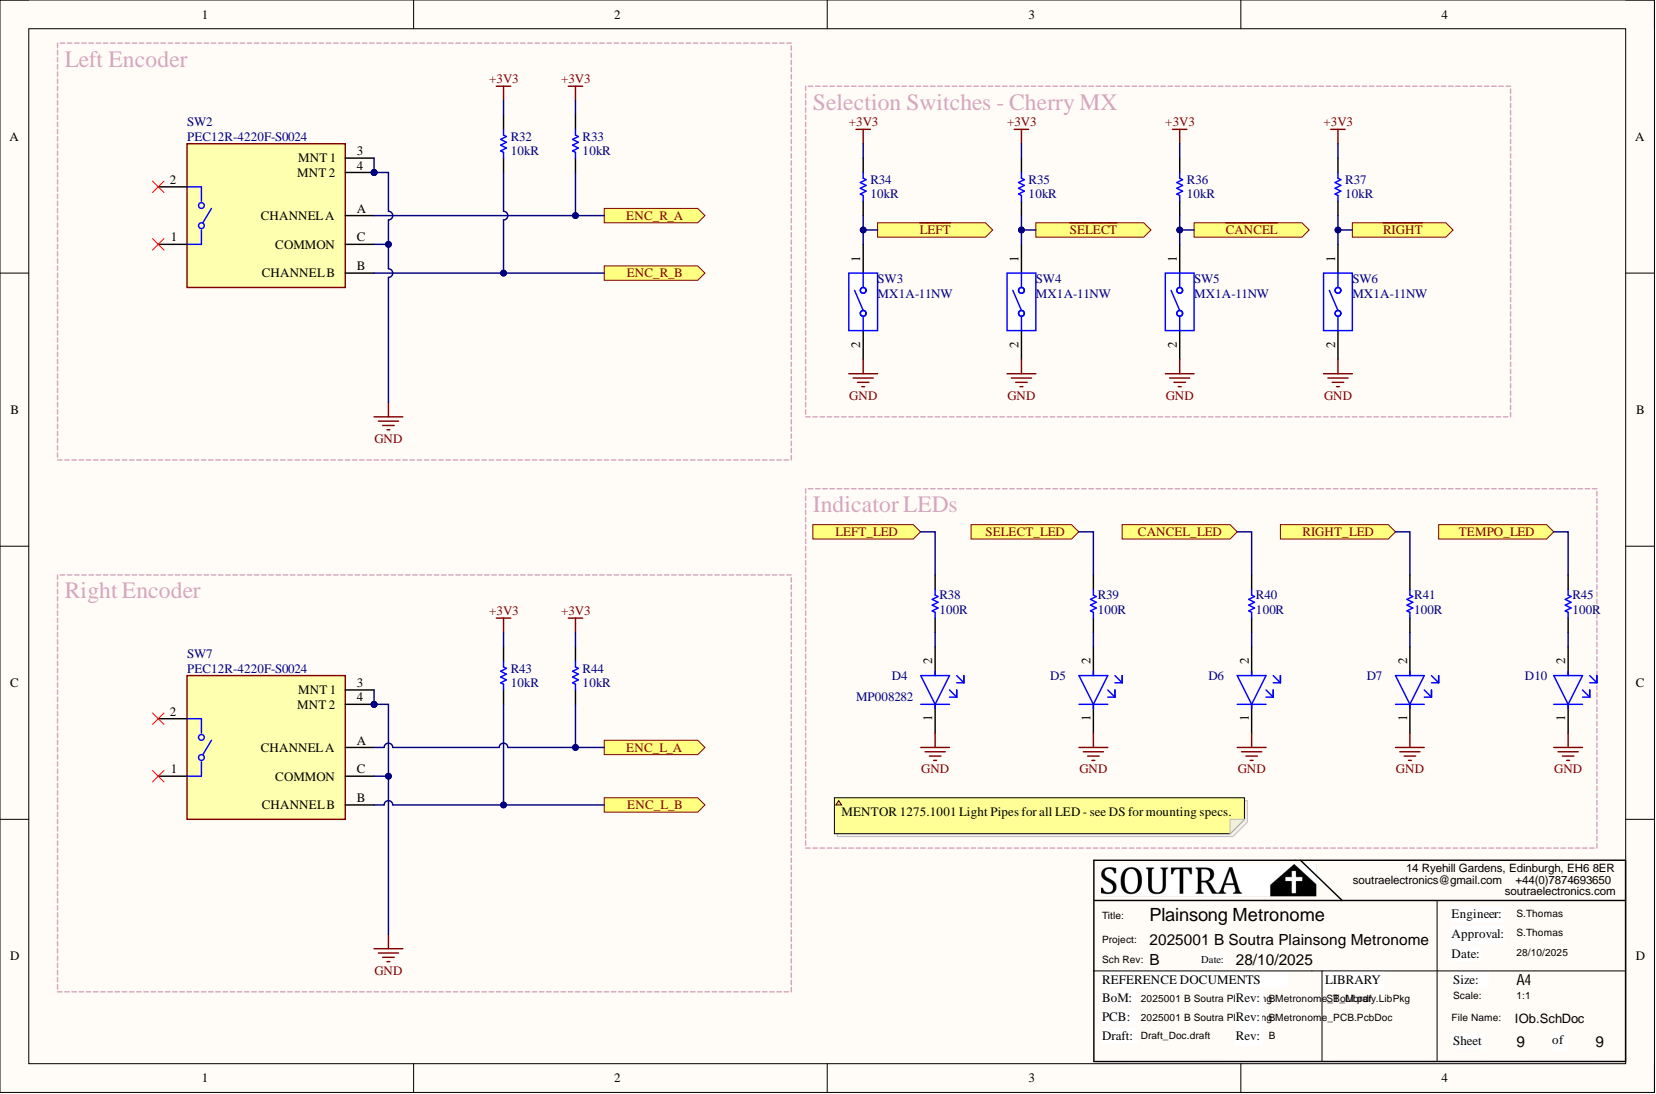
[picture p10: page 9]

Selection Switches - Cherry MX

MENTOR 1275.1001 Light Pipes for all LED - see DS for mounting specs.

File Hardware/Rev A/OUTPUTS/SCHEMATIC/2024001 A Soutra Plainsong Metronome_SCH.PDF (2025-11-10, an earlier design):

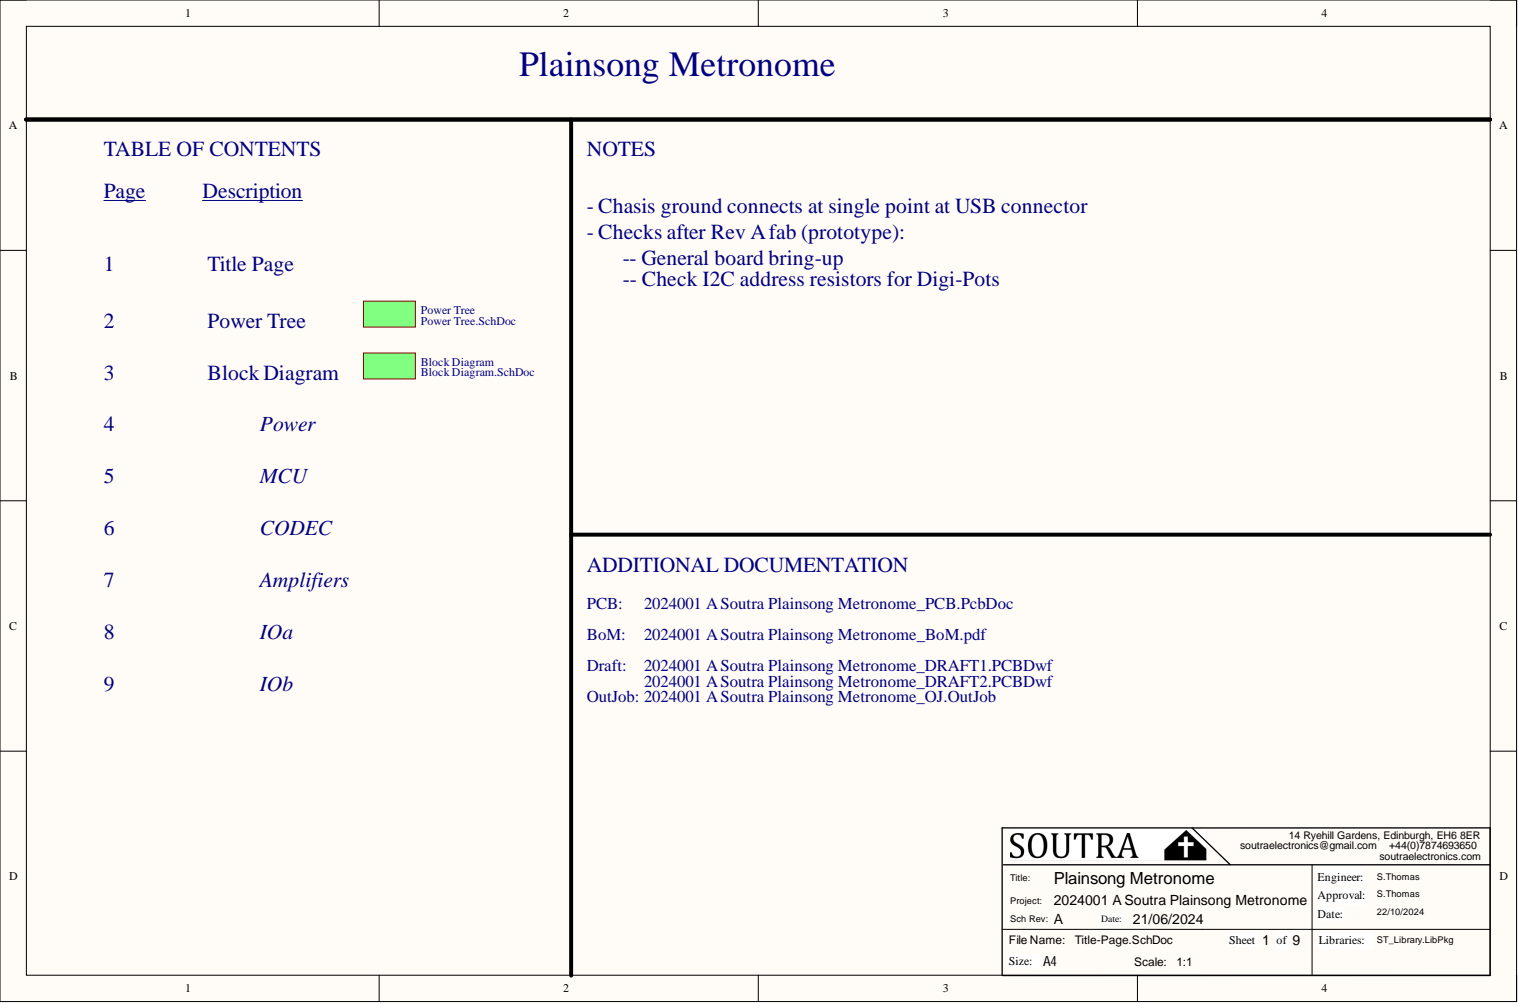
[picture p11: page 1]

- Chasis ground connects at single point at USB connector
- Checks after Rev Afab (prototype):
-- General board bring-up
-- Check I2C address resistors for Digi-Pots

Power Tree Power Tree.SchDoc

Block Diagram Block Diagram.SchDoc

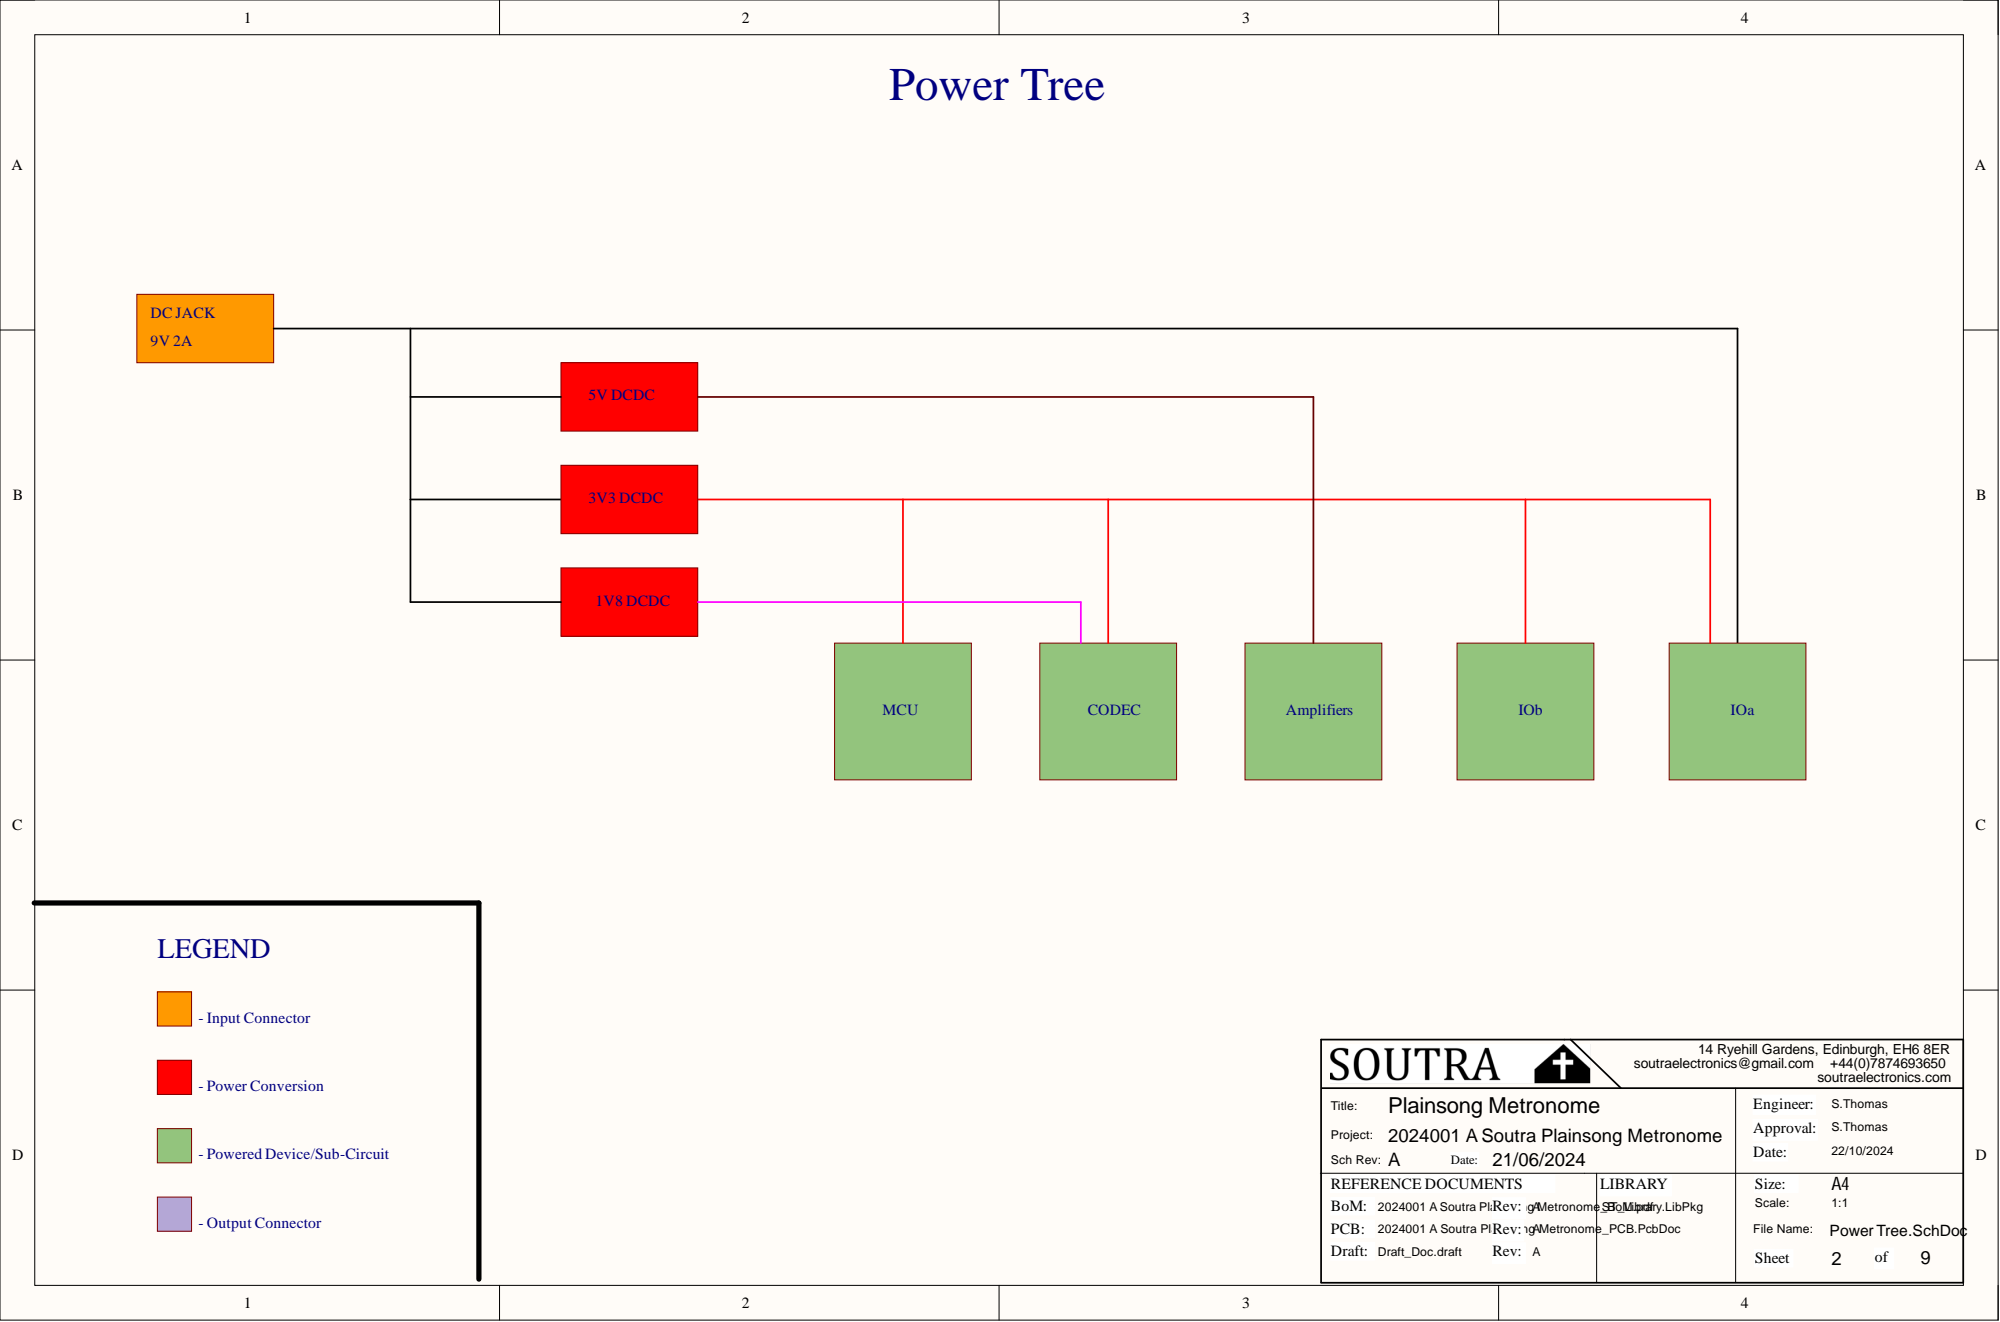
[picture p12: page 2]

- Powered Device/Sub-Circuit

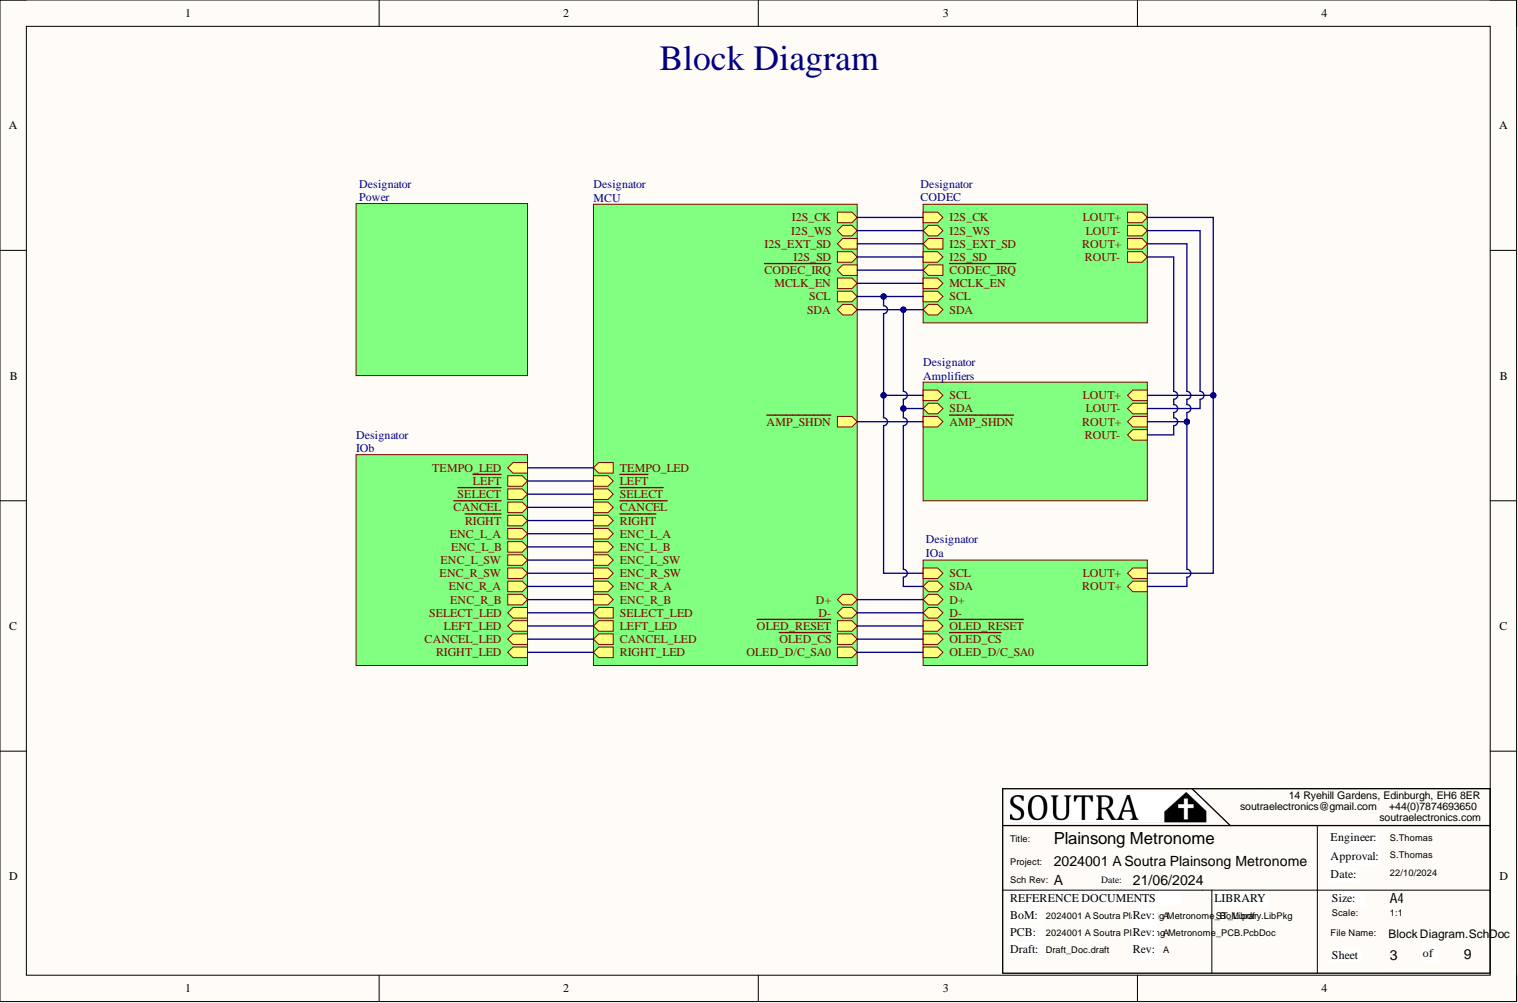
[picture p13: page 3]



VSSA/VREF- 8 VDDA/VREF+ 9



Rx no-fit - for digi-pot testing
only


3 0
3 1

Plainsong Metronome T itl e Pro j e ct: 2024001 A Soutra Plainsong Metronom e


Selection Switches - Cherry MX

MENTOR 1275.1001 Light Pipes for all LED - see DS for mounting specs.

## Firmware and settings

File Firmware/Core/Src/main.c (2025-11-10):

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
/* Includes ------------------------------------------------------------------*/
#include "main.h"
#include "cmsis_os.h"
#include "usb_device.h"

/* USER CODE BEGIN Includes */
#include "input_events.h"
#include "usbd_cdc_if.h"
#include "cmsis_os.h"      // STM32Cube abstraction over FreeRTOS
#include "queue.h"         // Required for queue functions like xQueueReceive
#include "oled.h"
/* USER CODE END Includes */

I2C_HandleTypeDef hi2c1;

I2S_HandleTypeDef hi2s2;

SPI_HandleTypeDef hspi1;

/* Definitions for Input_Task */
osThreadId_t Input_TaskHandle;
const osThreadAttr_t Input_Task_attributes = {
  .name = "Input_Task",
  .stack_size = 128 * 4,
  .priority = (osPriority_t) osPriorityAboveNormal2,
};
/* Definitions for UI_Control_Task */
osThreadId_t UI_Control_TaskHandle;
const osThreadAttr_t UI_Control_Task_attributes = {
  .name = "UI_Control_Task",
  .stack_size = 512 * 4,
  .priority = (osPriority_t) osPriorityAboveNormal,
};
/* Definitions for Metronome_Task */
osThreadId_t Metronome_TaskHandle;
const osThreadAttr_t Metronome_Task_attributes = {
  .name = "Metronome_Task",
  .stack_size = 256 * 4,
  .priority = (osPriority_t) osPriorityNormal,
};
/* Definitions for Audio_Out_Task */
osThreadId_t Audio_Out_TaskHandle;
const osThreadAttr_t Audio_Out_Task_attributes = {
  .name = "Audio_Out_Task",
  .stack_size = 512 * 4,
  .priority = (osPriority_t) osPriorityNormal,
};
/* Definitions for Screen */
osThreadId_t ScreenHandle;
const osThreadAttr_t Screen_attributes = {
  .name = "Screen",
  .stack_size = 512 * 4,
  .priority = (osPriority_t) osPriorityAboveNormal1,
};
/* Definitions for inputEventQueue */
osMessageQueueId_t inputEventQueueHandle;
const osMessageQueueAttr_t inputEventQueue_attributes = {
  .name = "inputEventQueue"
};
/* Definitions for defaultScreenQueue */
osMessageQueueId_t defaultScreenQueueHandle;
const osMessageQueueAttr_t defaultScreenQueue_attributes = {
  .name = "defaultScreenQueue"
};
/* Definitions for screenQueue */
osMessageQueueId_t screenQueueHandle;
const osMessageQueueAttr_t screenQueue_attributes = {
  .name = "screenQueue"
};
/* USER CODE BEGIN PV */
int bpm = 120;                 // Default BPM
int volume = 50;                // Default volume, scale e.g. 50–100
int metronome_running = 0;
char msg[64];					//char array for debug messages

typedef struct {
    uint8_t bpm;
    uint8_t volume;
    int is_playing;
} DefaultScreenData_t;

typedef enum {
    SCREEN_SETTINGS,
    SCREEN_DEFAULT,
    SCREEN_SAMPLES
} Screen_t;

/* USER CODE END PV */

void SystemClock_Config(void);
static void MX_GPIO_Init(void);
static void MX_I2C1_Init(void);
static void MX_I2S2_Init(void);
static void MX_SPI1_Init(void);
void Start_Input_Task(void *argument);
void Start_UI_Control_Task(void *argument);
void Start_Metronome_Engine_Task(void *argument);
void Start_Audio_Out_Task(void *argument);
void Screen_Task(void *argument);

/**
  * @brief  The application entry point.
  * @retval int
  */
int main(void)
{
  /* MCU Configuration--------------------------------------------------------*/

  /* Reset of all peripherals, Initializes the Flash interface and the Systick. */
  HAL_Init();

  /* Configure the system clock */
  SystemClock_Config();

  /* Initialize all configured peripherals */
  MX_GPIO_Init();
  MX_I2C1_Init();
  MX_I2S2_Init();
  MX_SPI1_Init();
  /* USER CODE BEGIN 2 */
  OLED_Init();
  OLED_DisplayStartupLogo();
  OLED_Clear();
  OLED_UpdateScreen();
  /* USER CODE END 2 */

  /* Init scheduler */
  osKernelInitialize();

  /* USER CODE BEGIN RTOS_MUTEX */
  /* add mutexes, ... */
  /* USER CODE END RTOS_MUTEX */

  /* USER CODE BEGIN RTOS_SEMAPHORES */
  /* add semaphores, ... */
  /* USER CODE END RTOS_SEMAPHORES */

  /* USER CODE BEGIN RTOS_TIMERS */
  /* start timers, add new ones, ... */
  /* USER CODE END RTOS_TIMERS */

  /* Create the queue(s) */
  /* creation of inputEventQueue */
  inputEventQueueHandle = osMessageQueueNew (50, 8, &inputEventQueue_attributes);

  /* creation of defaultScreenQueue */
  defaultScreenQueueHandle = osMessageQueueNew (50, 8, &defaultScreenQueue_attributes);

  /* creation of screenQueue */
  screenQueueHandle = osMessageQueueNew (50, 8, &screenQueue_attributes);

  /* USER CODE BEGIN RTOS_QUEUES */
  /* add queues, ... */
  /* USER CODE END RTOS_QUEUES */

  /* Create the thread(s) */
  /* creation of Input_Task */
  Input_TaskHandle = osThreadNew(Start_Input_Task, NULL, &Input_Task_attributes);

  /* creation of UI_Control_Task */
  UI_Control_TaskHandle = osThreadNew(Start_UI_Control_Task, NULL, &UI_Control_Task_attributes);

  /* creation of Metronome_Task */
  Metronome_TaskHandle = osThreadNew(Start_Metronome_Engine_Task, NULL, &Metronome_Task_attributes);

  /* creation of Audio_Out_Task */
  Audio_Out_TaskHandle = osThreadNew(Start_Audio_Out_Task, NULL, &Audio_Out_Task_attributes);

  /* creation of Screen */
  ScreenHandle = osThreadNew(Screen_Task, NULL, &Screen_attributes);

  /* USER CODE BEGIN RTOS_THREADS */
  /* add threads, ... */
  /* USER CODE END RTOS_THREADS */

  /* USER CODE BEGIN RTOS_EVENTS */
  /* add events, ... */
  /* USER CODE END RTOS_EVENTS */

  /* Start scheduler */
  osKernelStart();

  /* We should never get here as control is now taken by the scheduler */
  /* Infinite loop */
  /* USER CODE BEGIN WHILE */
  while (1)
  {
    /* USER CODE END WHILE */

    /* USER CODE BEGIN 3 */
  }
  /* USER CODE END 3 */
}

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
/* USER CODE BEGIN 4 */

//External int. callback
void HAL_GPIO_EXTI_Callback(uint16_t GPIO_Pin)
{
    switch (GPIO_Pin)
    {
        case N_SELECT_Pin:
            button_select_flag = 1;
            break;

        case N_CANCEL_Pin:
            button_stop_flag = 1;
            break;

        case N_LEFT_Pin:
            button_left_flag = 1;
            break;

        case N_RIGHT_Pin:
            button_right_flag = 1;
            break;

        case ENC_L_A_Pin:
        case ENC_L_B_Pin:
            // Read both pins to form current 2-bit state for left encoder
            currentState = (HAL_GPIO_ReadPin(ENC_L_A_GPIO_Port, ENC_L_A_Pin) << 1) |
                           HAL_GPIO_ReadPin(ENC_L_B_GPIO_Port, ENC_L_B_Pin);
            combined = (lastEncLeftState << 2) | currentState;

            switch (combined) {
                case 0b0001:
                case 0b0111:
                case 0b1110:
                case 0b1000:
                    encoder_left_delta = -1;
                    break;
                case 0b0010:
                case 0b0100:
                case 0b1101:
                case 0b1011:
                    encoder_left_delta = +1;
                    break;
                default:
                    // Invalid transition, could be noise, ignore
                    break;
            }
            lastEncLeftState = currentState;
            break;

        case ENC_R_A_Pin:
        case ENC_R_B_Pin:
            // Same for right encoder
            currentState = (HAL_GPIO_ReadPin(ENC_R_A_GPIO_Port, ENC_R_A_Pin) << 1) |
                           HAL_GPIO_ReadPin(ENC_R_B_GPIO_Port, ENC_R_B_Pin);
            combined = (lastEncRightState << 2) | currentState;

            switch (combined) {
                case 0b0001:
                case 0b0111:
                case 0b1110:
                case 0b1000:
                    encoder_right_delta = -1;
                    break;
                case 0b0010:
                case 0b0100:
                case 0b1101:
                case 0b1011:
                    encoder_right_delta = +1;
                    break;
                default:
                    // Noise, ignore
                    break;
            }
            lastEncRightState = currentState;
            break;

        default:
            break;
    }
}
/* USER CODE END 4 */

/* USER CODE BEGIN Header_Start_Input_Task */
/**
  * @brief  Function implementing the Input_Task thread.
  * @param  argument: Not used
  * @retval None
  */
/* USER CODE END Header_Start_Input_Task */
void Start_Input_Task(void *argument)
{
  /* init code for USB_DEVICE */
  MX_USB_DEVICE_Init();
  /* USER CODE BEGIN 5 */
  InputEvent_t evt;

  //Debounce timestamps (FreeRTOS ticks)
  uint32_t lastSelectPress = 0;
  uint32_t lastStopPress   = 0;
  uint32_t lastLeftPress   = 0;
  uint32_t lastRightPress  = 0;
  uint32_t lastEncLeft	   = 0;
  uint32_t lastEncRight	   = 0;

  const uint32_t debounceDelay = 150; //in ms
  const uint32_t encDebounceDelay = 10;
  /* Infinite loop */
  for(;;)
  {
	  //char msg[] = "Hello from Input_Task!\r\n";
	  //CDC_Transmit_FS((uint8_t*)msg, strlen(msg));
      uint32_t now = osKernelGetTickCount();

      if (button_select_flag) {
    	  button_select_flag = 0;
    	  if(now - lastSelectPress > debounceDelay){
    		  lastSelectPress = now;
    		  evt.type = EVENT_BUTTON_SELECT;
    		  evt.value = 0;
    		  osMessageQueuePut(inputEventQueueHandle, &evt, 0, 0);
    	  }
      }

      if (button_stop_flag) {
    	  button_stop_flag = 0;
    	  if(now - lastStopPress > debounceDelay){
			  lastStopPress = now;
			  evt.type = EVENT_BUTTON_STOP;
			  evt.value = 0;
			  osMessageQueuePut(inputEventQueueHandle, &evt, 0, 0);
    	  }
      }

      if (button_left_flag) {
    	  button_left_flag = 0;
    	  if(now - lastLeftPress > debounceDelay){
			  lastLeftPress = now;
			  evt.type = EVENT_BUTTON_LEFT;
			  evt.value = 0;
			  osMessageQueuePut(inputEventQueueHandle, &evt, 0, 0);
    	  }
      }

      if (button_right_flag) {
    	  button_right_flag = 0;
    	  if(now - lastRightPress > debounceDelay){
			  lastRightPress = now;
			  evt.type = EVENT_BUTTON_RIGHT;
			  evt.value = 0;
			  osMessageQueuePut(inputEventQueueHandle, &evt, 0, 0);
    	  }
      }

      if (encoder_left_delta != 0 && (now - lastEncLeft > encDebounceDelay)) {
          evt.type = EVENT_ENCODER_LEFT;
          evt.value = encoder_left_delta;
          encoder_left_delta = 0;
          lastEncLeft = now;
          osMessageQueuePut(inputEventQueueHandle, &evt, 0, 0);
      }

      if (encoder_right_delta != 0 && (now - lastEncRight > encDebounceDelay)) {
          evt.type = EVENT_ENCODER_RIGHT;
          evt.value = encoder_right_delta;
          encoder_right_delta = 0;
          lastEncRight = now;
          osMessageQueuePut(inputEventQueueHandle, &evt, 0, 0);
      }

      osDelay(1); // Run task every 10ms
  }
  /* USER CODE END 5 */
}

/* USER CODE BEGIN Header_Start_UI_Control_Task */
/**
* @brief Function implementing the UI_Control_Task thread.
* @param argument: Not used
* @retval None
*/
/* USER CODE END Header_Start_UI_Control_Task */
void Start_UI_Control_Task(void *argument)
{
  /* USER CODE BEGIN Start_UI_Control_Task */
	InputEvent_t evt;
	static int firstDraw = 1;
	Screen_t screen = SCREEN_DEFAULT;
    DefaultScreenData_t screenData = {
	    .bpm = bpm,
	    .volume = volume,
	    .is_playing = metronome_running
    };
	if ((SCREEN_DEFAULT) && (firstDraw == 1)) {
	    OLED_ShowDefaultScreen(bpm, volume, metronome_running);
	    firstDraw = 0;
	}
  for(;;)
  {
	  if (osMessageQueueGet(inputEventQueueHandle, &evt, NULL, osWaitForever) == osOK){
	      switch (evt.type)
	      	  {
				  case EVENT_ENCODER_LEFT:
					  bpm += evt.value;
					  if (bpm < 30) bpm = 30;
					  if (bpm > 300) bpm = 300;
					  sprintf(msg, "BPM: %d\r\n", bpm);
					  break;

				  case EVENT_ENCODER_RIGHT:
					  volume += evt.value;
					  if (volume < 0) volume = 0;
					  if (volume > 100) volume = 100;
					  sprintf(msg, "Volume: %d\r\n", volume);
					  break;

				  case EVENT_BUTTON_LEFT:
					  screen--;
					  if((screen > 0) && (screen != 1) && (screen != 2)){
						  screen = 0;
					  }
					  sprintf(msg, "Screen: %d\r\n", screen);
					  break;

				  case EVENT_BUTTON_RIGHT:
					  screen++;
					  if(screen >= 2){
						  screen = 2;
					  }
					  sprintf(msg, "Screen: %d\r\n", screen);
					  break;

				  case EVENT_BUTTON_SELECT:
					  sprintf(msg, "Starting metronome...\r\n");
					  if (!metronome_running)
					  {
						  //Metronome_Start(bpm, volume);
						  metronome_running = 1;
					  }
					  break;

				  case EVENT_BUTTON_STOP:
					  sprintf(msg, "Stopping metronome...\r\n");
					  if (metronome_running)
					  {
						  //Metronome_Stop();
						  metronome_running = 0;
					  }
					  break;

				  default:
					  break;
	              }
	          }
		  screenData.bpm = bpm;
		  screenData.volume = volume;
		  screenData.is_playing = metronome_running;

		  osMessageQueuePut(screenQueueHandle, &screen, 0, 0);
		  osMessageQueuePut(defaultScreenQueueHandle, &screenData, 0, 0);

	  	  CDC_Transmit_FS((uint8_t*)msg, strlen(msg));

	      osDelay(1); // Optional: prevent flooding
	  }
  /* USER CODE END Start_UI_Control_Task */
}

/* USER CODE BEGIN Header_Start_Metronome_Engine_Task */
/**
* @brief Function implementing the Metronome_Task thread.
* @param argument: Not used
* @retval None
*/
/* USER CODE END Header_Start_Metronome_Engine_Task */
void Start_Metronome_Engine_Task(void *argument)
{
  /* USER CODE BEGIN Start_Metronome_Engine_Task */
  /* Infinite loop */
  for(;;)
  {
	//char msg[] = "Hello from Metronome_Engine_Task!\r\n";
	//CDC_Transmit_FS((uint8_t*)msg, strlen(msg));
    osDelay(10);
  }
  /* USER CODE END Start_Metronome_Engine_Task */
}

/* USER CODE BEGIN Header_Start_Audio_Out_Task */
/**
* @brief Function implementing the Audio_Out_Task thread.
* @param argument: Not used
* @retval None
*/
/* USER CODE END Header_Start_Audio_Out_Task */
void Start_Audio_Out_Task(void *argument)
{
  /* USER CODE BEGIN Start_Audio_Out_Task */
  /* Infinite loop */
  for(;;)
  {
	//char msg[] = "Hello from Audio_Output_Task!\r\n";
	//CDC_Transmit_FS((uint8_t*)msg, strlen(msg));
    osDelay(10);
  }
  /* USER CODE END Start_Audio_Out_Task */
}

/* USER CODE BEGIN Header_Screen_Task */
/**
* @brief Function implementing the Screen thread.
* @param argument: Not used
* @retval None
*/
/* USER CODE END Header_Screen_Task */
void Screen_Task(void *argument)
{
  /* USER CODE BEGIN Screen_Task */
  /* Infinite loop */
  Screen_t currentScreen = SCREEN_DEFAULT;  // Start with default screen
  Screen_t newScreen;
  DefaultScreenData_t defaultData;

  for(;;)
  {
	  if (osMessageQueueGet(screenQueueHandle, &newScreen, NULL, osWaitForever) == osOK) {
		  currentScreen = newScreen;

		  // Flush the queue
		  if (currentScreen == SCREEN_DEFAULT) {
			   osMessageQueueReset(defaultScreenQueueHandle);
		  }
	  }
	  switch (currentScreen) {
		  case SCREEN_DEFAULT:
			  if(osMessageQueueGet(defaultScreenQueueHandle, &defaultData, NULL, osWaitForever) == osOK){
				  OLED_ShowDefaultScreen(defaultData.bpm,defaultData.volume,defaultData.is_playing);
			  }
			  break;
		  case SCREEN_SETTINGS:
			  OLED_ShowSettingsScreen();
			  break;
		  case SCREEN_SAMPLES:
			  OLED_ShowSamplesScreen();
			  break;
	  }
    osDelay(1);
  }
  /* USER CODE END Screen_Task */
}

/**
  * @brief  Period elapsed callback in non blocking mode
  * @note   This function is called  when TIM2 interrupt took place, inside
  * HAL_TIM_IRQHandler(). It makes a direct call to HAL_IncTick() to increment
  * a global variable "uwTick" used as application time base.
  * @param  htim : TIM handle
  * @retval None
  */
void HAL_TIM_PeriodElapsedCallback(TIM_HandleTypeDef *htim)
{
  if (htim->Instance == TIM2) {
    HAL_IncTick();
  }
}

/**
  * @brief  This function is executed in case of error occurrence.
  * @retval None
  */
void Error_Handler(void)
{
  /* USER CODE BEGIN Error_Handler_Debug */
  /* User can add his own implementation to report the HAL error return state */
  __disable_irq();
  while (1)
  {
  }
  /* USER CODE END Error_Handler_Debug */
}

#ifdef  USE_FULL_ASSERT
/**
  * @brief  Reports the name of the source file and the source line number
  *         where the assert_param error has occurred.
  * @param  file: pointer to the source file name
  * @param  line: assert_param error line source number
  * @retval None
  */
void assert_failed(uint8_t *file, uint32_t line)
{
  /* USER CODE BEGIN 6 */
  /* User can add his own implementation to report the file name and line number,
     ex: printf("Wrong parameters value: file %s on line %d\r\n", file, line) */
  /* USER CODE END 6 */
}
#endif /* USE_FULL_ASSERT */

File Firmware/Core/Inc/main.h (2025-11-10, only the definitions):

#define OLED_RESET_Pin GPIO_PIN_14
#define OLED_RESET_GPIO_Port GPIOC
#define MCLK_EN_Pin GPIO_PIN_0
#define MCLK_EN_GPIO_Port GPIOA
#define CANCEL_LED_Pin GPIO_PIN_3
#define CANCEL_LED_GPIO_Port GPIOA
#define N_LEFT_Pin GPIO_PIN_0
#define N_LEFT_GPIO_Port GPIOB
#define N_LEFT_EXTI_IRQn EXTI0_IRQn
#define N_RIGHT_Pin GPIO_PIN_1
#define N_RIGHT_GPIO_Port GPIOB
#define N_RIGHT_EXTI_IRQn EXTI1_IRQn
#define N_SELECT_Pin GPIO_PIN_2
#define N_SELECT_GPIO_Port GPIOB
#define N_SELECT_EXTI_IRQn EXTI2_IRQn
#define ENC_L_B_Pin GPIO_PIN_13
#define ENC_L_B_GPIO_Port GPIOB
#define RIGHT_LED_Pin GPIO_PIN_8
#define RIGHT_LED_GPIO_Port GPIOA
#define LEFT_LED_Pin GPIO_PIN_9
#define LEFT_LED_GPIO_Port GPIOA
#define N_FLASH_RESET_Pin GPIO_PIN_10
#define N_FLASH_RESET_GPIO_Port GPIOA
#define SELECT_LED_Pin GPIO_PIN_13
#define SELECT_LED_GPIO_Port GPIOA
#define TEMPO_LED_Pin GPIO_PIN_14
#define TEMPO_LED_GPIO_Port GPIOA
#define N_AMP_SHDN_Pin GPIO_PIN_15
#define N_AMP_SHDN_GPIO_Port GPIOA
#define ENC_L_A_Pin GPIO_PIN_3
#define ENC_L_A_GPIO_Port GPIOB
#define ENC_L_A_EXTI_IRQn EXTI3_IRQn
#define ENC_R_A_Pin GPIO_PIN_4
#define ENC_R_A_GPIO_Port GPIOB
#define ENC_R_A_EXTI_IRQn EXTI4_IRQn
#define ENC_R_B_Pin GPIO_PIN_5
#define ENC_R_B_GPIO_Port GPIOB
#define ENC_R_B_EXTI_IRQn EXTI9_5_IRQn
#define N_CANCEL_Pin GPIO_PIN_8
#define N_CANCEL_GPIO_Port GPIOB
#define N_CANCEL_EXTI_IRQn EXTI9_5_IRQn
#define N_CODEC_IRQ_Pin GPIO_PIN_9
#define N_CODEC_IRQ_GPIO_Port GPIOB
#define N_CODEC_IRQ_EXTI_IRQn EXTI9_5_IRQn

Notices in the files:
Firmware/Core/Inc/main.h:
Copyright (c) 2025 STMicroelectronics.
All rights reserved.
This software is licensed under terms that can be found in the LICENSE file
